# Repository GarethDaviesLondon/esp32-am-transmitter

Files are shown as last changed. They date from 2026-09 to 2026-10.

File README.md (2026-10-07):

# ESP32-S3 AM Transmitter

An ESP32-S3 plays internet radio over Wi-Fi and re-broadcasts it as an
amplitude-modulated longwave carrier on a GPIO pin, so an ordinary AM receiver
in the same room picks it up. Two independent transmitters, two stations, one
board. It is driven entirely from a web page it serves itself, or from a serial
console, and it lives in a 3D-printed case whose lid is the antenna.

**[There is a project page with a demo video.](https://garethdavieslondon.github.io/esp32-am-transmitter/)**

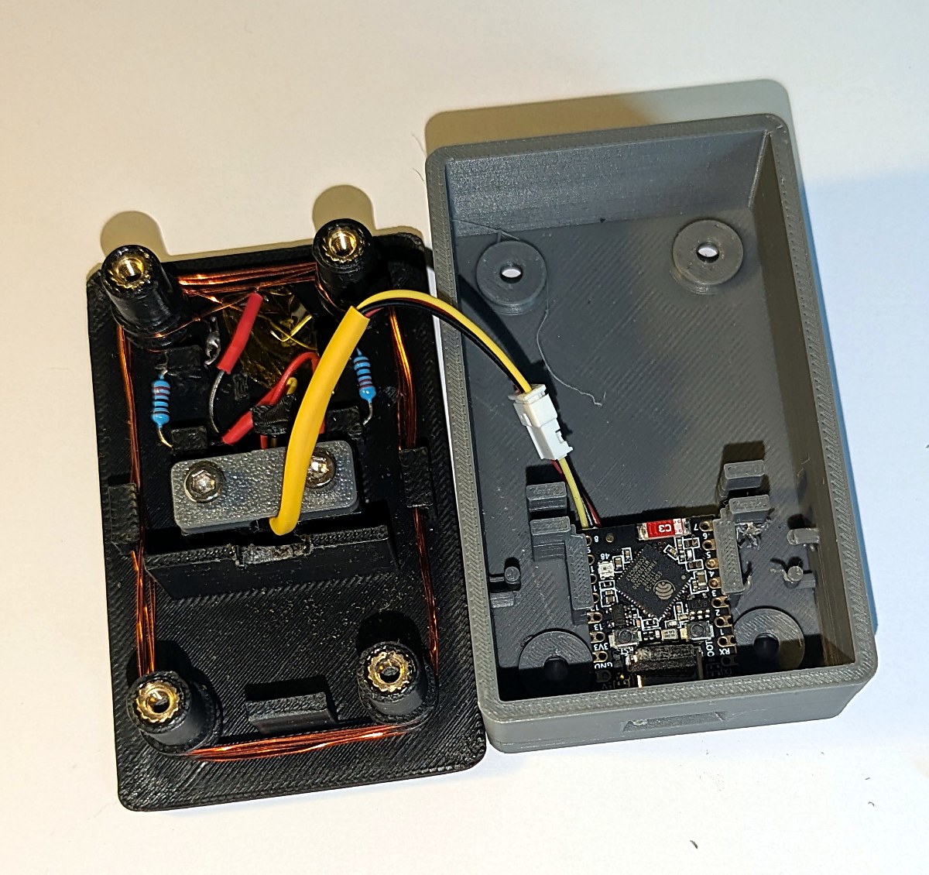
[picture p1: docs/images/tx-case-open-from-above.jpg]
The transmitter, open


## Read this before you build one

**This is a radio transmitter, and two facts about it are not negotiable.**

- **It transmits in a licensed broadcast band.** The default carrier is
  200 kHz, which is inside the longwave broadcast band, 2 kHz from BBC Radio 4
  on 198 kHz. Deliberate radiation there is licensed in the UK and in most
  other countries, and this project holds no licence. It is built to be heard
  by a receiver on the same table: an inductive loop beside the radio, not an
  antenna. **What you radiate, and the rules where you live, are yours to
  check.**
- **There is no output filter in this build.** The carrier is a square wave,
  so it radiates odd harmonics at 600 kHz, 1 MHz and upward, across the whole
  medium-wave band. At this power, with the loop next to the receiver, that
  was judged acceptable by ear. **It has never been measured on a spectrum
  analyser.** Raise the drive, lengthen the antenna or drop the series
  resistor and the harmonics rise with it. The Technical Manual gives a
  low-pass network to fit if you do.

## How it is wired

The as-built wiring

Per transmitter: a GPIO pin, a 220 ohm resistor, a five-turn loop wound on the
lid's pillars, back to ground. The two chains share the ground and nothing
else.

## What it does

- **Two transmitters.** Separate stations, carrier frequencies, modulation
  depth, audio low-pass, gain, carrier level and power-on station. They share
  one Wi-Fi connection and one station list.
- **Proper AM.** Duty-cycle modulation linearised through an arcsine table,
  because the obvious scheme barely modulates at all. A 6th-order low-pass,
  a fractional resampler with a fill controller, a peak limiter and a loudness
  AGC that brings stations within about 2 dB of each other.
- **A web interface** for everything: stations, directory search, both
  transmitters' settings, a test tone, Wi-Fi, diagnostics.
- **A serial console** that can do everything the page can, so a board whose
  network is broken is still reachable over USB.
- **Carrier level and fading**, if you want it to sound like a distant station.
- **A printed case** whose lid carries both loop windings on four pillars.

## Quick start: flash a board

You need a Waveshare ESP32-S3-Zero (or another ESP32-S3), a USB-C data cable,
and Python.

```
pip install esptool
python -m esptool --chip esp32s3 -p COM5 write_flash 0x0 binaries/amtx-v1.0-merged.bin
```

Use your own port (`/dev/ttyACM0` and similar elsewhere), and the board's own
USB-C socket rather than a separate serial adapter.

Then power it up, join the Wi-Fi network **`AMTX-Setup`** it raises, and follow
the page that opens.

If that was too terse, **[docs/manuals/quick_start.pdf](docs/manuals/quick_start.pdf)**
is the same journey with every step spelled out: installing Python, which of
the board's two USB sockets to use, the flashing tool in `tools/esp-flasher`,
proving the firmware is running by typing `help` at the `amtx>` console, and
both ways of putting the board on your network. No compiler needed.

## Build one

**[docs/manuals/build_manual.pdf](docs/manuals/build_manual.pdf)** is the
end-to-end guide: parts, printing, heat-set inserts, winding the antenna,
wiring, assembly, flashing, first boot, and what to do when it does not work.

| Manual | For |
| --- | --- |
| [Quick Start](docs/manuals/quick_start.pdf) | Release zip to a transmitter on the air, no toolchain. Start here |
| [Build](docs/manuals/build_manual.pdf) | Making one from parts |
| [Installation](docs/manuals/installation_manual.pdf) | Toolchain, building the firmware from source, flashing |
| [User](docs/manuals/user_manual.pdf) | Driving it once it runs |
| [Technical](docs/manuals/technical_manual.pdf) | How the firmware works, for changing it |

## What is in here

```
firmware/     ESP-IDF v5.3 project: the whole transmitter
tools/        Desktop tools, Python + tkinter:
                esp-serial-monitor   serial console, system and CLI panes split
                esp-flasher          finds, probes, flashes and monitors a board
                amtx-programmer      the flasher plus a tab that sets the board up
case/          The printed case: STEP for editing, STL for printing
binaries/      A flashable build, merged and as separate images
docs/          The manuals, as PDF and Markdown
```

## What has actually been tested

This project tries to be honest about the difference between "built" and
"proven". As of v1.0:

- **Runs on hardware.** Two stations playing at once, heard on an AM receiver,
  each decoder sustaining full rate with the modulator never starving. The web
  interface, the console, station switching, Wi-Fi joining and the diagnostics
  have all been used on a real board.
- **Printed and assembled.** The case has been printed and built more than
  once. The current revision fixes what the last print got wrong; **it has not
  itself been printed yet**, and nothing in it needs support.
- **Not measured.** Nothing has been on a spectrum analyser or a scope. The
  harmonic content, radiated field strength and modulation depth are unknown.
- **Not tested on hardware:** the factory-reset button gesture (hold BOOT for
  five seconds). The code is built and the other two routes to the same
  function are straightforward, but nobody has pressed the button yet.

## Licence

GPL-3.0. See [LICENSE](LICENSE).

The MP3 decoder (libhelix) is fetched by the build from the ESP component
registry and carries its own licence. The board's dimensions came from
Waveshare's published drawing for the
[ESP32-S3-Zero](https://www.waveshare.com/wiki/ESP32-S3-Zero), which is not
reproduced here.

## About this repository

It is the public mirror of a working repository where the engineering record
lives: design documents, the registers of known issues and lessons, the
parametric CAD source for the case, and the reasoning behind each decision.
What is published here is the product: source, tools, manuals, geometry and a
binary.

Issues and pull requests are welcome, though development happens elsewhere and
lands here in releases.

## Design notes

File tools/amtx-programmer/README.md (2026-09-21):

# Tool: amtx-programmer

## Purpose

Sets up an AM transmitter board from a PC, over USB, without the web page.

It is `esp-flasher` with one more tab. The flasher finds the board, reads what
is on it and writes firmware. The **Program** tab then configures the running
transmitter with buttons and dialogs: what each transmitter plays, its RF
settings, the station list, Wi-Fi, the hostname, and whether the web interface
is on at all. Every button sends a command to the board's `amtx>` serial
console and shows the reply.

It is for the cases the web page cannot cover: a board with the web interface
turned off, a board not yet on any network, or several boards to set up one
after another.

## In this project

- The commands are the ones in `docs/design/07_console_and_access.md` §2. The
  firmware must include them. On older firmware the tab connects, but most
  buttons answer "unrecognised command (is the firmware older than design
  07?)". Flash a current build first; the Flash section above the tab does
  that.
- The board's console is on native USB. The tab holds the port while it is
  connected, so it closes any monitor tab on the same board when you press
  **Connect**, and lets go while the flasher probes or flashes. Opening a
  monitor tab on the board takes the port back from the Program tab.
- After a reboot or a flash the board drops off the bus. The tab reconnects by
  itself when it comes back, for up to 20 seconds.

## Usage

```
pip install -r tools/amtx-programmer/requirements.txt
python tools/amtx-programmer/amtx_programmer.py
```

1. Plug the board in and select it in the board list at the top.
2. Open the **Program** tab and press **Connect**. The tab reads the board's
   state and fills in every sub-tab.
3. Use the sub-tabs:
   - **Transmitters**: what A and B are playing, Stop, Play a URL, every RF
     setting with **Apply and save**, and the test tone.
   - **Stations**: the shared list. Play on A or B, Add, Delete, Move up and
     down, level Trim, and the power-on station for each transmitter.
   - **Discover**: search Radio-Browser by name, genre or country, then play a
     result or save it to the list.
   - **Network and access**: Wi-Fi scan, join, save and forget; the hostname;
     turning the web interface on or off; the board's log output.
   - **Console log**: every command sent and every reply line, with log lines
     from the board marked `[SYS]`. A box at the bottom sends any command by
     hand.
4. **Refresh** reads the state again. It also happens after every change.
   Tick "Refresh every 5 s" to keep the view live.

Every reply shows in the status bar at the bottom of the tab. A command that
fails also opens a dialog saying why.

Without a board:

```
python tools/amtx-programmer/amtx_programmer.py --sim      # the GUI against a simulated board
python tools/amtx-programmer/amtx_programmer.py --check    # build the window, connect to the simulation, exit
```

One command from the command line, no window:

```
python tools/amtx-programmer/amtx_programmer.py --port COM5 --run "state"
python tools/amtx-programmer/amtx_programmer.py --run "station list"
```

## Files

The Program tab is split by panel: each mixin owns the widgets it builds, the
part of the state document it renders, and what its buttons do. Adding a
control means opening the file named after the thing it controls.

| File | Holds |
| ---- | ----- |
| `amtx_programmer.py` | the command line and the window |
| `amtx_console.py` | the console as a request and reply protocol, no Tk in it |
| `programmer_config.py` | constants, and the flasher and monitor imports |
| `programmer_tab.py` | the Program tab: connection, worker thread, refresh |
| `programmer_transmitters.py` | the two transmitter panels and the test tone |
| `programmer_stations.py` | the station list panel |
| `programmer_discover.py` | the Radio-Browser panel |
| `programmer_network.py` | Wi-Fi, hostname, web interface, reboot |
| `programmer_dialogs.py` | the form dialog they all ask with |
| `fake_board.py` | a simulated board, for the tests and `--sim` |

## How it talks to the console

`amtx_console.py` is the protocol, with no GUI in it:

- **A reply ends at `ok` or `error:`** for every command design 07 added.
- **`wifi`** ends with one too. `wifi join` and `wifi scan` wait up to 25
  seconds for it, because a join can be silent for 15.
- **`status`, `log` and `reboot`** print no such line. Their reply ends when
  the console prints its `amtx>` prompt again, which the REPL does before
  reading every line, or after a short quiet period if the prompt never shows.
  `reboot` ends at "rebooting" or when the port drops.
- **The console asks the terminal where its cursor is** (`ESC[6n`) before
  every line, and waits for the answer with no timeout, reading anything sent
  meanwhile as the answer. The reader answers those queries itself, as the
  monitor's terminal does. Without that, commands are swallowed.
- **Log lines are separated** with `esp-serial-monitor`'s `ConsoleSplitter`,
  imported, not copied.
- **On connecting** it sends an empty line and waits for a fresh prompt, which
  also clears anything half-typed in the console.

`fake_board.py` is a model of that console, for the tests and for `--sim`: a
smart and a dumb terminal mode, coloured log lines in the middle of replies,
the REPL's own error trailer, and a reboot that takes the port away. Where the
firmware's wording differs from it, the firmware is right.

## Tests

The repo's root `python -m pytest` collects only `cad/` and `designs/`, so run
these by path:

```
python -m pytest tools/amtx-programmer
```

34 tests: text parsing, every command in both terminal modes against the
fake board, a failure not leaking into the next reply, a disconnect in the
middle of a command, reboot and reconnect, and the Program tab itself driven
with its window hidden. The GUI tests skip where Tk cannot open a window.

## Dependencies

- `pyserial` and `esptool`, through `tools/esp-flasher/requirements.txt`.
- `tools/esp-flasher/` and `tools/esp-serial-monitor/` must sit beside this
  directory; the program imports both.
- `pytest`, for the tests only.

## Redeployable?

`partly`. `amtx_console.py`'s reply handling suits any ESP-IDF `esp_console`
REPL whose commands print a final `ok` or `error:` line; `PROMPT` and the
legacy command list are the project-specific parts. The Program tab and
`fake_board.py` are this firmware's command set and nothing else.

## What has been verified

- **In this session, with no board:** the test suite passes (34 tests, run
  more than twenty times in a row after the last change). `--check` builds the
  window, connects to the simulated board and shows its stations.
- **Not verified:** nothing has run against a real board. The firmware with
  the design 07 commands had not been flashed anywhere when this was written,
  so every reply format here comes from the design document and ESP-IDF's
  REPL source, not from a board. The dialogs have been built and driven by the
  tests but not looked at by a person.
- One test run failed, once, before the `--check` test moved into its own
  process, and its output was not captured. A second Tk window in the same
  process had also been failing to start intermittently at that point, which
  is the likely cause, but it is not proven.

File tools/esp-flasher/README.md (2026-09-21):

# Tool: esp-flasher

## Purpose

A flashing console for ESP32 boards that works out what the board needs
instead of making you know. It:

1. **Watches the USB bus** and flags a board that keeps dropping off it, which
   is what a blank or corrupt ESP32-S3 on native USB does.
2. **Catches the board in download mode**, retrying on every reappearance, so a
   boot-looping board can be reached without holding BOOT.
3. **Reads back what is on the flash** (bootloader, partition table, app
   description) and compares each with the build you picked.
4. **Recommends what to write**: bootloader, partition table and app when the
   board is blank or its layout differs, the app alone when the rest already
   matches. It refuses a build for the wrong chip or a bigger flash.
5. **Flashes it** with esptool, and **opens a serial monitor tab** that follows
   the board through resets, so you see it boot and can use the `amtx>` CLI.

The monitor tabs are `tools/esp-serial-monitor`'s, imported rather than copied,
with reconnection added.

## In this project

- Pick the `build/` directory that `idf.py build` produced. The tool reads
  `build/flasher_args.json`, so it writes the same three images at the same
  offsets and flash settings `idf.py flash` would.
- The board is on native USB (`303A:1001`). The tool tracks it by the USB
  serial number, which is the chip's MAC, so it follows the board even if
  Windows hands it a different COM number after a reset. The baud rate is
  cosmetic on this port.
- A **new, blank board** shows `boot-looping (resets every 2.6s)` in the board
  list. On the bus for about 2.2 s, then gone for 0.4 s, while the ROM prints
  `invalid header: 0xffffffff` until the watchdog resets it. See `LL-06`.

## Usage

GUI (the normal way):

```
python tools/esp-flasher/esp_flasher.py
```

1. **Board.** Plug the board in; it appears in the list (a looping one too).
   Press **Probe board**. The probe is read-only; it reports the chip, flash
   size, MAC, and the state of each region against the selected build. A board
   with an app is reset back into it; a blank one is left in download mode,
   where it stops looping and stays on the bus.
2. **Firmware.** The newest `build*/` directory under the repo is preselected.
   **Build folder...** picks another, **.bin file...** picks a single image
   (a merged image goes at 0x0, anything else at the offset in the box).
3. **Flash.** Leave **Auto** on and press **Flash**. If the board has not been
   probed, it is probed first. A confirmation lists exactly what will be
   written and why. **Erase whole flash first** also wipes NVS: saved Wi-Fi
   networks and settings.
4. When the board comes back on the bus, a **Monitor** tab opens on it: logs
   and boot output in the `[SYS]` pane on top, the `amtx>` console in the
   terminal pane below (click it and type). If the board resets, the tab
   reconnects by itself unless you closed the port.

Command line, for the same operations without the window:

```
python tools/esp-flasher/esp_flasher.py --list              # ESP boards on the bus
python tools/esp-flasher/esp_flasher.py --watch 10          # appear/vanish log, spots a boot loop
python tools/esp-flasher/esp_flasher.py --builds            # build directories found
python tools/esp-flasher/esp_flasher.py --probe             # what is on the board vs the newest build
python tools/esp-flasher/esp_flasher.py --flash             # probe, confirm, write what it needs
python tools/esp-flasher/esp_flasher.py --flash --mode app --port COM5 --build build -y
```

A probe of a blank board, as seen on the second bench board (2026-09-16):

```
ESP32-S3 (QFN56) (revision v0.2)  MAC aa:bb:cc:dd:ee:ff  flash 4MB
Features: Wi-Fi, BT 5 (LE), Dual Core + LP Core, 240MHz, Embedded Flash 4MB (XMC), Embedded PSRAM 2MB (AP_3v3)
Bootloader: blank
Partition table: blank
App: no app partition to look in
Board left in download mode (it will not run until flashed or reset).
Recommended: full (the board has no bootloader)
```

## Files

| File | Holds |
| ---- | ----- |
| `esp_flasher.py` | the command line, and the names amtx-programmer imports |
| `flasher_config.py` | constants, the monitor and esptool imports, `Cancelled` |
| `flasher_images.py` | parsing an image header, an app description, a partition table |
| `flasher_firmware.py` | a build on disk, and finding builds |
| `flasher_bus.py` | watching the USB bus, spotting a boot loop (`LL-06`) |
| `flasher_probe.py` | catching the board, reading it back, comparing with a build |
| `flasher_esptool.py` | running esptool, and its v4/v5 differences |
| `flasher_ui.py` | the window, and the monitor tab that reconnects |

## Dependencies

```
pip install -r tools/esp-flasher/requirements.txt
```

- `esptool` (v4.7 or v5) and `pyserial`. Probing uses esptool as a library;
  flashing runs `python -m esptool` as a child process, so Stop can kill it and
  its output streams into the log.
- `tools/esp-serial-monitor/esp_serial_monitor.py` must sit beside this
  directory; the monitor tabs come from it.
- The ESP-IDF Python environment already has both packages, so the tool also
  runs from an `export.ps1` shell.

## Redeployable?

`yes`, together with `esp-serial-monitor`. Nothing is specific to this project:
the image layout comes from the build's `flasher_args.json` and the image
headers. Worth a `TUNE:` look for another board:

- `CHIP_IDS`: the image-header chip ids recognised; an unknown one is shown by
  number and still flashes.
- `CONNECT_TIMEOUT`, `PORT_POLL_SECONDS`, `LOOP_WINDOW_SECONDS`: tuned for an
  S3 that is off the bus for 0.4 s per loop.

## Notes

- **The tool closes its own monitor tab before probing or flashing** and
  reopens it afterwards. A terminal in another program still blocks the port;
  close it first.
- **Auto recommends app-only only when the bootloader and partition table on
  the board are byte-identical to the build's.** Anything else gets a full
  flash, which is always safe.
- **A changed partition table can orphan NVS.** The recommendation says so;
  tick Erase if the board misbehaves after a layout change.
- **Early boot lines can be missed.** Native USB re-enumerates after the reset
  that follows a flash, and nothing is read until the port is back. Press the
  board's RESET with the tab open to see a whole boot.
- **If the board cannot be caught** within 25 s, put it in download mode by
  hand: hold BOOT, press and release RESET, release BOOT, then probe again.
- **What has been exercised on hardware:** listing, bus watch, probing a blank
  board (CLI and GUI), the GUI's plan, and a monitor tab opening. Not
  exercised: catching a board **while** it boot-loops using this finished tool
  (the same retry loop did catch it in a prototype on the second attempt),
  the flash itself, the post-flash reconnect, and esptool v4.

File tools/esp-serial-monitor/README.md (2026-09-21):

# Tool: esp-serial-monitor

## Purpose

A serial console for ESP32/ESP8266 development boards that answers the two
questions a terminal program makes you answer first: **which port is the board
on, and what baud rate is it talking at?** It lists the ports, marks the ones
whose USB adapter belongs to an ESP board, probes a port to work out its baud
rate from the traffic itself, and opens a monitor tab per board with keyboard
entry back to the device.

Each monitor tab has **two panes**. The top one collects **system messages**,
each line prefixed `[SYS]`: ESP-IDF log lines (`I (1234) wifi: ...`, coloured
by level), ROM banners (`rst:`, `invalid header`) and crash dumps, plus the
monitor's own notices. The bottom one is a **terminal for the board's
console**: click in it and type, PuTTY style. It understands the escape
sequences ESP-IDF's line editor sends and answers its terminal probe, so arrow
keys, history and TAB completion work.

It removes the loop of guessing a COM port, guessing 115200, seeing garbage and
guessing again. It also watches several boards at once in one window, which
`pio device monitor` will not do and a mesh or multi-node bring-up needs.

## In this project

The board is an ESP32-S3 with the console on **USB Serial/JTAG**, not a UART
(`CONFIG_ESP_CONSOLE_USB_SERIAL_JTAG=y` in `sdkconfig.defaults`). Two
consequences when you use this tool here:

- The port shows up as `Espressif native USB (JTAG/serial)` (VID `0x303A`, PID
  `0x1001`), already in `KNOWN_ADAPTERS`, so it is flagged as a likely ESP board
  without any tuning.
- **The baud rate is cosmetic.** It is a USB CDC link, so any rate works and
  "Detect baud..." has nothing real to measure. Open the monitor at 115200 and
  ignore the rate; the tool says the same thing when it recognises the adapter.

Reset-pulse caveat: the native USB port has no DTR/RTS auto-reset transistors,
so "Reset board while probing" does nothing here. Press the board's EN button,
or reflash, to see the boot banner.

The value of the tool on this project is the multi-board case: with two
transmitters under test, or a board and a receiver-side jig, it watches both in
one window, which `idf.py monitor` will not do. It is also the way to read the
log when `idf.py monitor` is unavailable (no ESP-IDF export in that shell, or a
Windows session outside the IDF environment).

## Usage

GUI (the normal way):

```
python3 tools/esp-serial-monitor/esp_serial_monitor.py
```

1. **Boards** lists every serial port, likely ESP boards first, with the adapter
   it recognised (CP210x, CH340, FTDI, or the S2/S3/C3 native USB). Tick
   "Likely ESP boards only" to hide Bluetooth and modem ports.
2. Select a port and click **Detect baud...** if you do not know the rate. It
   tries each candidate rate in turn, scores what comes back for readability,
   and ranks them. Double-click the winning row to open a monitor at that rate.
3. Or set the rate yourself and click **Open monitor**. Select several ports and
   they all open, one tab each.
4. Click in the **Console** pane and type. Every keystroke goes to the board as
   you press it: the arrow keys as ANSI sequences, TAB for completion, Ctrl+C
   as `0x03` (or a copy, when text is selected), Ctrl+V pastes to the board.
   What appears is the board's own echo. **Enter sends** CR by default, which
   is what ESP-IDF's console reads as Enter; switch it to LF or CRLF for
   firmware that wants those. The **Send line** box under the pane sends a
   whole line at once, with its own history.
5. System messages land in the top pane as they arrive, even in the middle of a
   half-typed command, so the console stays readable. Untick **Split system
   messages** to see the raw interleaved stream in the terminal instead.

Command line, for the same discovery without the window:

```
$ python3 tools/esp-serial-monitor/esp_serial_monitor.py --list
PORT       ADAPTER                            ESP?    DESCRIPTION
COM18      Espressif native USB (JTAG/serial) yes     USB Serial Device (COM18)
           USB VID:PID=303A:1001 SER=AA:BB:CC:DD:EE:FF
COM3       Bluetooth virtual port             -       Standard Serial over Bluetooth link (COM3)

$ python3 tools/esp-serial-monitor/esp_serial_monitor.py --detect COM18
Probing COM18 (Espressif native USB (JTAG/serial))
  Trying 115200 baud...
  115200 baud: 412 bytes, score 1.10
  Confident match at 115200 baud; stopping.

BAUD      BYTES   PRINTABLE  SCORE  SAMPLE
115200    412     100%       1.10   I (325) cpu_start: Pro cpu up. | I (330) app_main: running

Best match: 115200 baud.
```

`--detect` with no port picks the board itself if exactly one is plugged in.
Other flags: `--bauds 115200,74880` to probe a specific list, `--seconds` to
listen longer at each rate, `--no-reset` to listen without restarting the board,
`--all-bauds` to probe every rate instead of stopping at the first confident
match, `--esp-only` to filter `--list`.

### What each monitor tab gives you

| Control | Does |
| --- | ---- |
| Baud + Apply | change rate on a live port, without reopening it |
| DTR / RTS | drive the control lines by hand, for boards with unusual wiring |
| Reset board | pulse the auto-reset circuit so you see the boot banner |
| Send break | assert a UART break, for firmware that uses one as a signal |
| Close port / Reopen | free the port for a flash, then pick the session back up |
| Split system messages | route log lines, ROM output and crash dumps to the `[SYS]` pane; off sends everything to the terminal |
| Timestamps | prefix each system line with local time to the millisecond |
| Hex view | 16-column hex dump of every byte in the system pane, for binary protocols |
| Pause | freeze the display while the port keeps draining |
| Log file | append to a file as it arrives: `[SYS]` system lines, `[CLI]` finished console lines |
| Enter sends | CR, LF or CRLF, for the Enter key in the terminal and the Send line box |
| Escapes | interpret `\n`, `\r`, `\t`, `\0`, `\xHH` in the Send line box |
| Local echo | also show what the Send line box sent, for firmware that does not echo |

## Files

One job per module. `esp_serial_monitor.py` is the command line and the front
door, and the names other tools use are re-exported from it, so
`import esp_serial_monitor as monitor` keeps working whatever moves below.

| File | Holds |
| ---- | ----- |
| `esp_serial_monitor.py` | the command line, and the public surface |
| `monitor_config.py` | constants, and whether pyserial is installed |
| `monitor_ports.py` | finding, describing and opening a port |
| `monitor_baud.py` | working out a board's baud rate by listening |
| `monitor_session.py` | one open port, read on its own thread |
| `monitor_split.py` | telling log output from console output |
| `monitor_terminal.py` | the VT100 subset linenoise needs |
| `monitor_text.py` | key names, escapes, hex rows, timestamps |
| `monitor_tab.py` | one board's tab and its two panes |
| `monitor_app.py` | the window, the port list, the detect dialog |

Module names are prefixed `monitor_` because these tools are scripts on
`sys.path` rather than packages: the flasher puts its own directory and this
one on the path together, and two modules with the same name would shadow each
other.

## Dependencies

```
pip install -r tools/esp-serial-monitor/requirements.txt
```

- `pyserial` for port enumeration and I/O. Everything else is the standard
  library (`tkinter`; on some Linux distributions install it separately with
  `sudo apt install python3-tk`).
- Linux users need to be in the `dialout` group to open a port, or every open
  fails with a permission error.
- No network access. The tool writes to the board only what you type, plus the
  reset pulse when you ask for one.

## Redeployable?

`yes`. No project-specific paths and nothing to tune for a normal ESP project.
Two constants are worth a `TUNE:` look for an unusual board:

- `KNOWN_ADAPTERS`: add the VID/PID of a bridge chip the project's boards use if
  it is not in the list. An unlisted adapter still works; it just is not flagged
  as a likely ESP board.
- `DEFAULT_PROBE_BAUDS` / `COMMON_BAUDS`: trim to the rates the project's
  firmware actually uses to make detection quicker.

If the project pins a `monitor_speed` in `platformio.ini`, that is the rate the
firmware talks at; detection is for the boards where nobody wrote it down.

Neither was tuned for this project: `KNOWN_ADAPTERS` already carries the S3's
native-USB VID/PID, and the probe list is irrelevant on a USB CDC link.

The two-pane monitor (the system/console split and the terminal emulation) was
added here, after the tool was installed from the catalogue, so the live copy
is now ahead of the catalogue copy. None of it is project-specific: it keys on
the ESP-IDF log format and the escape sequences of ESP-IDF's `linenoise`, so it
back-ports as is.

## Notes

- **Detection needs the port free and the board talking.** It opens the port
  exclusively, so close any other monitor first (the tool says so plainly when
  the open fails). If the firmware prints nothing at boot, every rate comes back
  silent and the tool says that rather than guessing.
- **The reset pulse assumes the standard auto-reset wiring** (DTR to IO0, RTS to
  EN). It holds IO0 high so the board restarts into the application, not the ROM
  bootloader. A board without those transistors ignores it; untick "Reset board
  while probing" and detection just listens.
- **On the S2/S3/C3 native USB port the baud rate is cosmetic.** It is a USB CDC
  link, not a real UART, so any rate works and the tool says so. Baud only
  matters on a board with a separate bridge chip.
- **A board that sends non-ASCII log output scores lower** than a plain ASCII
  one, because the score rewards printable bytes. Read the sample column rather
  than trusting the score alone.
- Opening a port resets many boards, whatever this tool does with DTR/RTS: that
  is the adapter's wiring, not the software. Expect to see a boot banner.
- The tool never flashes firmware. Close the port (or the tab) before flashing,
  or the flasher cannot claim it.
- Each pane keeps the last 5000 lines. Turn on a log file for a long run.
- **How a line is judged a system message:** it starts with the ESP-IDF log
  format (`I (1234) tag: `, optionally coloured), or with a known ROM or panic
  prefix (`rst:`, `ESP-ROM:`, `Guru Meditation`, `Backtrace:` and so on), or a
  coloured log line starts in the middle of console text. Text that might be
  the start of one is held back for at most 0.15 s, so typing does not lag.
  With `CONFIG_LOG_COLORS` off, a log line printed over a half-typed prompt is
  not recognised and stays in the terminal.
- **The terminal emulates a small VT100 subset:** CR, LF, backspace, tab,
  erase in line, cursor movement, clear screen, colours, and the `ESC[5n` /
  `ESC[6n` status queries. That is what ESP-IDF's console uses. A full-screen
  program would need more.
- **Line editing depends on the probe at boot.** ESP-IDF asks the terminal
  whether it understands escape sequences when the console starts. If no
  terminal was listening then (the port was closed during boot), the console
  falls back to "dumb" mode for that boot: typing still works, but the arrow
  keys and history do not. Reboot with the tab open to get line editing.

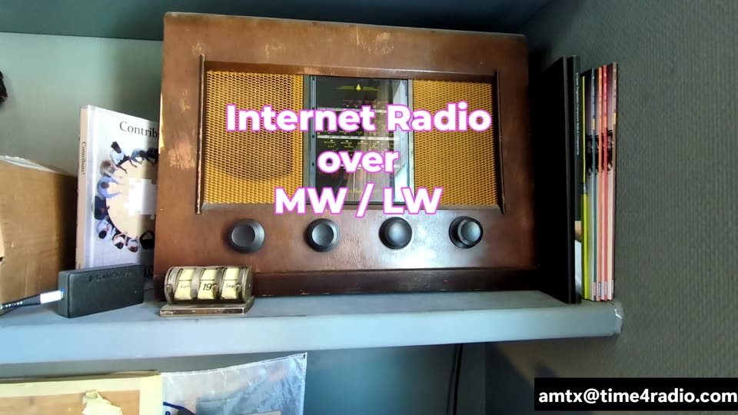
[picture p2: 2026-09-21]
docs/media/amtx-demo-poster.jpg

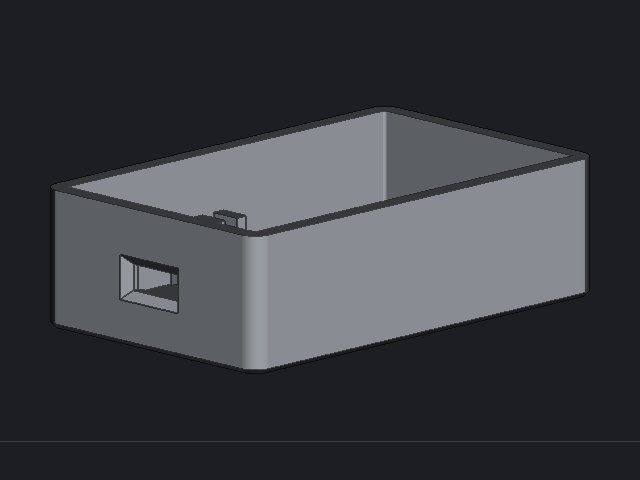
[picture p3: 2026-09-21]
docs/images/renders/base.jpg

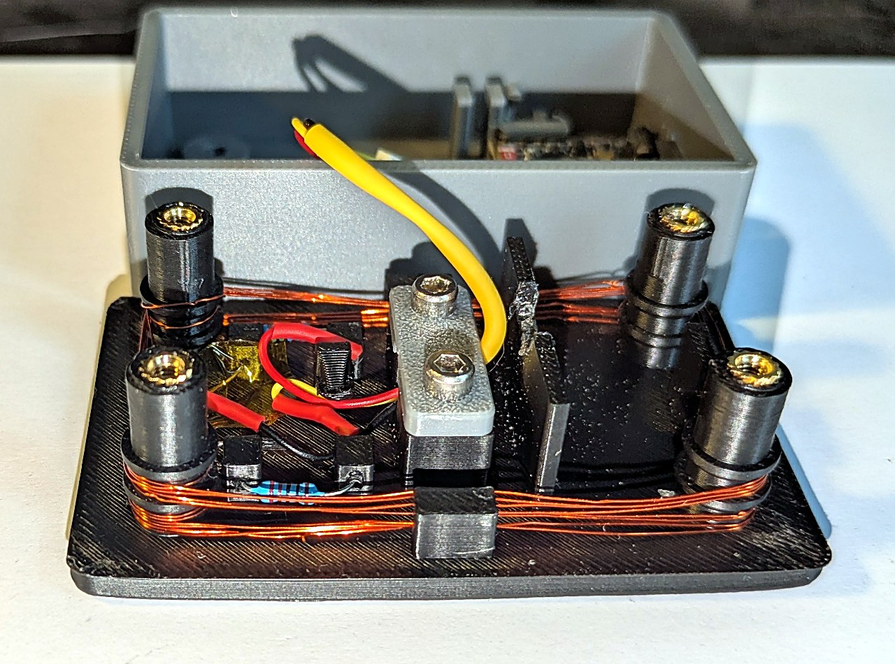
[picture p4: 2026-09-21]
docs/images/tx-case-windings-close.jpg

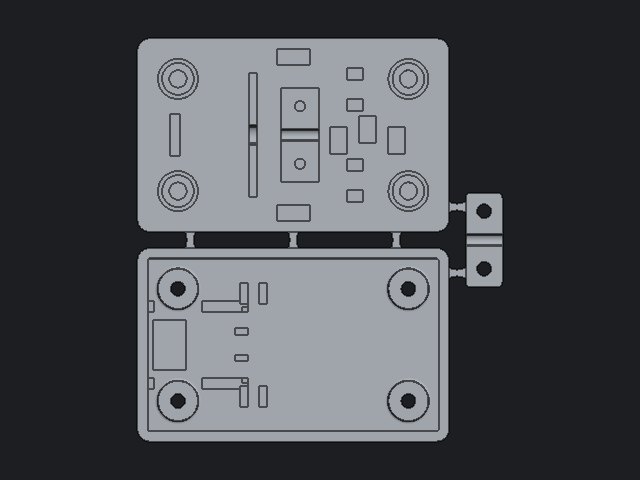
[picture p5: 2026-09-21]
docs/images/renders/sprue.jpg

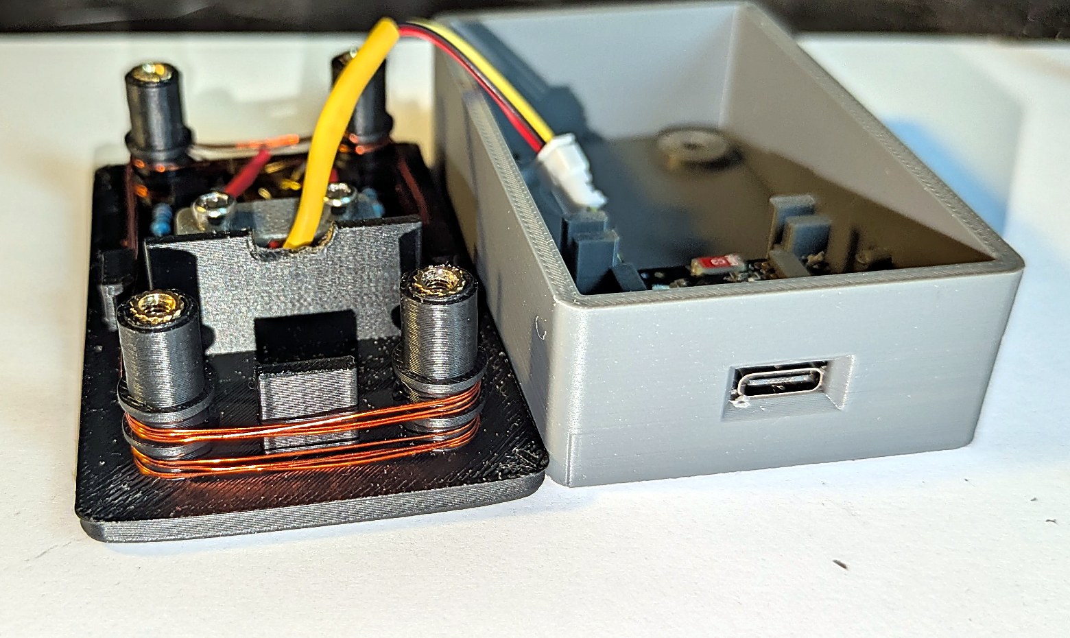
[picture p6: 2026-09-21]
docs/images/tx-case-lid-and-base.jpg

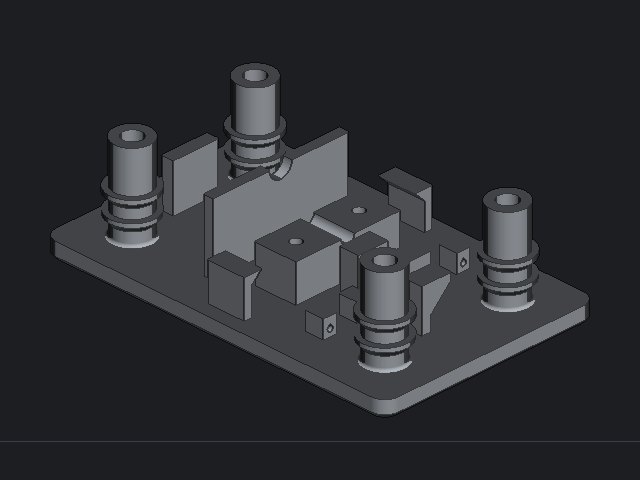
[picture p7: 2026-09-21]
docs/images/renders/lid.jpg

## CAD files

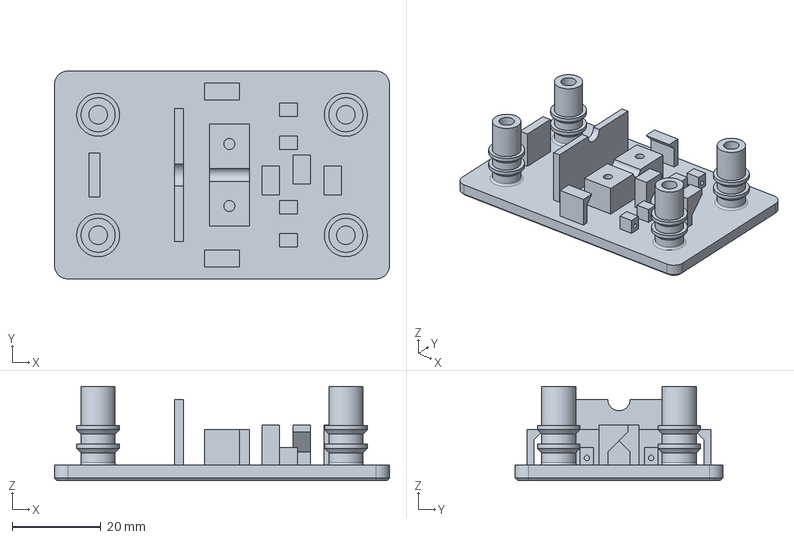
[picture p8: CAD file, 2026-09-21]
case/tx-case.lid.step
75.6 x 46.9 x 21.3 mm

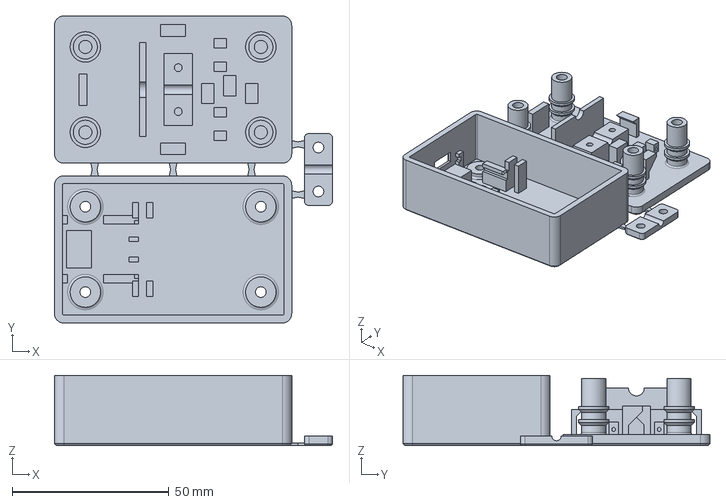
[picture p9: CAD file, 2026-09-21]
case/tx-case.sprue.step
88.6 x 97.8 x 22.3 mm

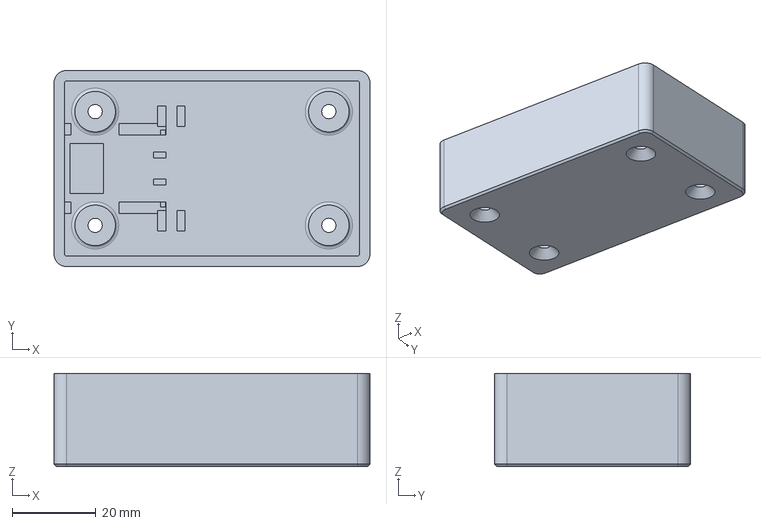
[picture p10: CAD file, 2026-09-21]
case/tx-case.base.step
75.6 x 46.9 x 22.3 mm

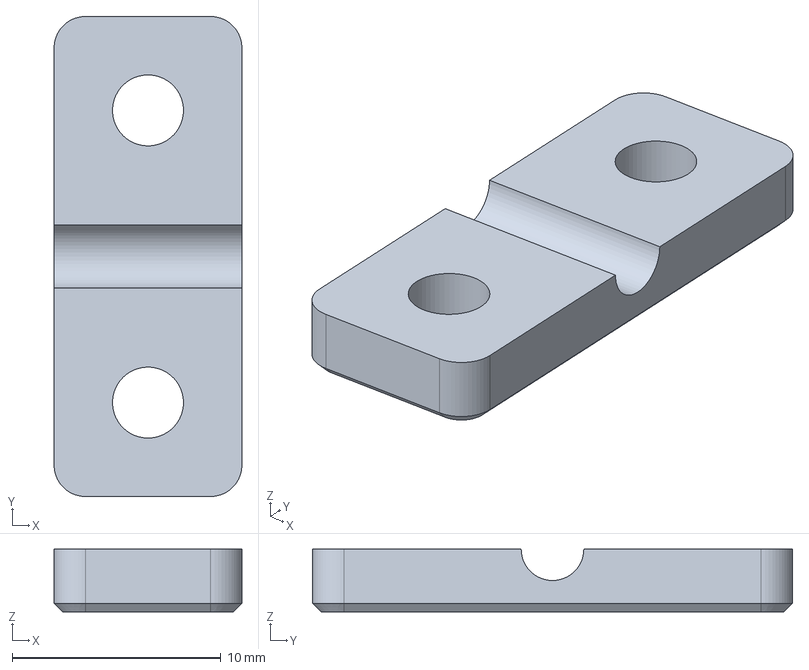
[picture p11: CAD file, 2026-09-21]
case/tx-case.clamp.step
9.00 x 23.0 x 3.00 mm

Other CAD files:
case/tx-case.base.stl
case/tx-case.clamp.stl
case/tx-case.lid.stl
case/tx-case.sprue.stl

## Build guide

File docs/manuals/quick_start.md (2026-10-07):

# Quick Start

From a downloaded release to a transmitter playing internet radio, with no
compiler and no ESP-IDF. About twenty minutes, most of it waiting for
downloads.

This is the short path. It flashes a firmware binary that is already built.
If you want to change the firmware and build it yourself, read the
Installation Manual instead. To make the case and wind the antennas, read the
Build Manual.

## Contents

1. What you need
2. Get the release
3. Install Python
4. Plug the board in
5. Flash it
6. Talk to the board
7. Put it on your Wi-Fi
8. Hear something
9. Before you leave it running
10. When it goes wrong

## 1. What you need

| Item | Notes |
| ---- | ----- |
| An ESP32-S3 board | 8 MB flash. A bare "mini" dev board is fine. No display, no audio hardware, no buttons needed |
| A USB cable | Data, not charge-only. A charge-only cable looks like a dead board |
| A Wi-Fi network | 2.4 GHz. The board has no 5 GHz radio |
| An AM receiver | Longwave capable, if you keep the default 200 kHz and 250 kHz carriers |
| A PC | Windows, macOS or Linux |

You do **not** need the 3D-printed case, the loop antennas or any soldering to
get to the end of this guide. The board will transmit a few centimetres on its
own, which is enough to prove it works with a receiver sitting next to it.

### One thing to get right before anything else

Your board probably has two USB sockets. One is a USB-to-serial bridge
(CH343, CP210x or similar). The other is the ESP32-S3's own USB peripheral.

**Use the native USB port.** The firmware puts its console there. On the
bridge you will see the ROM bootloader banner and nothing else, and you will
conclude the board is broken when it is not.

On Windows the native port appears in Device Manager as
`USB JTAG/serial debug unit`, with a `USB Serial Device` COM number. On Linux
it is usually `/dev/ttyACM0`, on macOS `/dev/cu.usbmodem*`.

If the board has only one socket, that is the native one.

## 2. Get the release

Go to the [latest release](https://github.com/GarethDaviesLondon/esp32-am-transmitter/releases/latest)
and download the **source code zip**, not just the loose `.bin` files. The zip
carries the flashing tool as well as the firmware, and you want both.

Unzip it anywhere. You will end up with a directory holding, among other
things:

```
binaries/
  amtx-v1.0-merged.bin        the firmware, everything in one file
tools/
  esp-flasher/                the flashing tool you are about to run
  esp-serial-monitor/         the serial terminal it uses
docs/
  manuals/                    this guide and the other four
```

The version number in the `.bin` filename will match the release you
downloaded, so `amtx-v1.0-merged.bin` may read `v1.1` or later. Use whatever
is actually there.

## 3. Install Python

The flashing tool is a Python program. It needs **Python 3.10 or newer**.

- **Windows:** install from [python.org](https://www.python.org/downloads/).
  On the first screen of the installer, tick **Add python.exe to PATH**. This
  is the step everybody misses, and without it the commands below report
  `python: command not found`.
- **macOS:** `brew install python`, or the python.org installer.
- **Linux:** Python 3 is already there. You also need Tk, which is packaged
  separately: `sudo apt install python3-tk` on Debian or Ubuntu. Without it
  the tool stops with `ModuleNotFoundError: No module named 'tkinter'`.

Check it:

```
python --version
```

If that reports Python 2, or nothing, try `python3 --version` and use
`python3` everywhere below.

Now install the two packages the tool needs. From the directory you unzipped:

```
pip install -r tools/esp-flasher/requirements.txt
```

That is `pyserial`, which finds the board, and `esptool`, which writes the
flash. Nothing else.

## 4. Plug the board in

Connect the board's native USB port to the PC.

**A brand-new board will look broken.** A blank ESP32-S3 has nothing to boot,
so the ROM gives up and the watchdog resets it, about every 2.6 seconds. On
native USB that means the board appears on the bus, vanishes, and appears
again, over and over. Windows may chime repeatedly. This is correct behaviour
for an empty board and the flasher is built to cope with it.

## 5. Flash it

Change into the flasher's directory and run it:

```
cd tools/esp-flasher
python esp_flasher.py
```

Note the underscore in `esp_flasher.py`.

A window opens with three sections: Board, Firmware, Flash.

1. **Board.** Your board is in the list. A new one is labelled something like
   `boot-looping (resets every 2.6s)`, which is the tool telling you it has
   noticed the loop in §4. Select it and press **Probe board**.

   The probe only reads. It reports the chip, the flash size, the MAC address,
   and what is currently in each region. A blank board reports
   `Bootloader: blank` and is left in download mode, where it stops looping
   and sits still on the bus.

2. **Firmware.** The tool preselects the newest `build*/` directory it can
   find. **A release download has no `build/` directory**, so there will be
   nothing selected or the wrong thing selected. Press **`.bin` file...** and
   choose `binaries/amtx-v1.0-merged.bin` from the unzipped release.

   The tool recognises a merged image and places it at offset `0x0` by itself.
   You do not need to touch the offset box.

3. **Flash.** Leave **Auto** ticked and press **Flash**. A confirmation lists
   exactly what it is about to write and why. Accept it.

   Writing takes a few seconds. Leave **Erase whole flash first** unticked:
   on a new board there is nothing to erase, and on a used board it also wipes
   saved Wi-Fi networks and settings.

When the board comes back on the bus, a **Monitor** tab opens on it by itself.

### If you would rather not use the tool

The flasher is the friendlier route, but the plain `esptool` command does the
same job in one line, and it is the route that has had the most use on real
hardware:

```
pip install esptool
python -m esptool --chip esp32s3 -p COM5 write_flash 0x0 binaries/amtx-v1.0-merged.bin
```

Replace `COM5` with your port. On Linux that is `/dev/ttyACM0`, on macOS
`/dev/cu.usbmodem*`.

## 6. Talk to the board

The Monitor tab has two panes. Boot output and log messages scroll in the
`[SYS]` pane on top. The console is the terminal pane below.

**Click the lower pane before you type.** Keystrokes go to whichever pane has
focus, and typing into the log pane does nothing at all, which is a
dispiriting way to start.

You should see the board boot, join nothing yet, and settle. Press Enter and
you get the prompt:

```
amtx>
```

Log messages keep scrolling past while you type, which makes the console hard
to read. Turn them off:

```
amtx> log off
```

Now check the firmware is really running and talking to you:

```
amtx> help
```

That lists every command the board understands, in alphabetical order. You
should see `play`, `station`, `rf`, `tone`, `discover`, `wifi`, `hostname`,
`web`, `status`, `state`, `log`, `factory-reset` and `reboot`.

**If `help` lists those commands, the firmware is on the board and working.**
That is the milestone. Everything from here is configuration.

One more worth trying, because it prints the whole state of the board on one
line:

```
amtx> status
```

## 7. Put it on your Wi-Fi

The board has no network yet. There are two ways to give it one. They reach
the same result and save to the same place, so use whichever suits you.

### Option A: the setup page, from a phone

Best if you are away from the PC, or setting up a board that is already in its
case.

With no saved network, the board raises its own open Wi-Fi access point called
**`AMTX-Setup`**.

1. On a phone or laptop, join `AMTX-Setup`. It has no password.
2. The setup page opens by itself, as a captive portal. If it does not, open a
   browser and go to `http://192.168.4.1`.
3. Press **Scan**, pick your network, type its password, and save.
4. The board reboots and joins.

Once it has joined, the access point goes away and the board is at
**`http://amtx.local`**, or at the address shown on the page's Network tab.
That page is the full interface: stations, both transmitters, RF settings,
diagnostics.

### Option B: the console, from the PC

Best if you are already sitting at the Monitor tab, which you are.

See what is in range:

```
amtx> wifi scan
```

You get a numbered list with signal strengths:

```
 0  MyNetwork                        -52 dBm  secured
 1  BTWifi-X                         -78 dBm  open
ok: 2 network(s) found
```

Then join, which also saves:

```
amtx> wifi join MyNetwork mypassword
```

It prints `joining "MyNetwork" ...`, takes up to fifteen seconds, and then
tells you what happened:

```
joined "MyNetwork", ip 192.168.1.42, rssi -52 dBm
ok: joined MyNetwork, ip 192.168.1.42, saved (1 stored)
```

Put double quotes round anything containing a space:

```
amtx> wifi join "My Home Network" "pass phrase with spaces"
```

Useful companions:

| Command | Does |
| --- | ---- |
| `wifi status` | Where it is now, and its address |
| `wifi list` | The networks it has saved |
| `wifi save <ssid> [pass]` | Save for next boot without joining now |
| `wifi forget` | Delete every saved network |

A joined board prints its address. Open `http://amtx.local` in a browser and
you have the web interface, the same as Option A.

## 8. Hear something

A factory-fresh board comes up with two stations already in its list, one on
each transmitter:

| Transmitter | Default station | Default carrier |
| --- | --- | --- |
| A | Radio Swiss Jazz | 200 kHz |
| B | BBC World Service | 250 kHz |

So once it is on your network it should already be transmitting. Check with:

```
amtx> status
```

Now tune a receiver. Put it next to the board, switch it to **longwave**, and
tune slowly around 200 kHz. Without an antenna the range is a few centimetres,
so the receiver needs to be touching or nearly touching the board.

If you are hunting for the carrier and want something unmistakable, a steady
tone is far easier to find than music:

```
amtx> tone a on 1000
```

That replaces the programme on transmitter A with a 1 kHz tone. Find it on the
dial, then put the music back:

```
amtx> tone a off
```

Heard it? That is the whole chain working: Wi-Fi, the stream, the decoder, the
modulator and the carrier.

For everything you can do from here, read the User Manual.

## 9. Before you leave it running

Two things to understand, and they are not formalities.

**It transmits in a licensed broadcast band.** Longwave runs from 148.5 kHz to
283.5 kHz. The default 200 kHz carrier sits inside it, a couple of kilohertz
from BBC Radio 4's allocation on 198 kHz. Deliberate radiation there needs a
licence in the UK and in most other places, and this project has none. Keep
the field inside the room: no outdoor wire, nothing connected to mains wiring,
nothing resembling a real antenna. What you radiate, and the rules where you
live, are yours to check.

**There is no output filter in a bare-board build.** The carriers are square
waves, and a square wave at 200 kHz radiates odd harmonics at 600 kHz, 1.0 MHz
and upward, across the whole medium-wave band. For a few minutes on a bench
with a receiver beside it, that is tolerable. For anything left running, fit
the series resistor and low-pass network for each carrier pin, as the Build
Manual describes. Each carrier needs its **own** filter: one filter shared
between both lets them intermodulate.

## 10. When it goes wrong

| What you see | What it is |
| --- | --- |
| `python: command not found` on Windows | Python was installed without **Add python.exe to PATH**. Re-run the installer and tick it |
| `No module named 'tkinter'` | Linux, missing Tk. `sudo apt install python3-tk` |
| No board in the list | Charge-only cable, or the wrong USB socket. See §1 |
| Only the ROM banner, no `amtx>` prompt | You are on the USB-to-serial bridge, not the native port. See §1 |
| Board appears and vanishes repeatedly | Normal for a blank board. Flash it. See §4 |
| `Could not open COM5, the port is busy` | Something else holds the port. Close other terminals. A terminal whose window you closed can leave its process running |
| Nothing selected in the Firmware section | Expected on a release download: there is no `build/` directory. Press **`.bin` file...**. See §5 |
| The flasher cannot catch the board | Put it in download mode by hand: hold BOOT, press and release RESET, release BOOT, then probe again |
| `unrecognised command` from a command in §6 | The firmware on the board is older than this guide. Flash the release binary |
| Typing does nothing in the Monitor tab | Click the lower pane first. See §6 |
| Joined Wi-Fi but `amtx.local` will not open | Use the IP address from `wifi status`. Some networks and some Windows setups do not resolve `.local` names |
| No audio, carrier present | The station URL may be dead. Try `station list`, then `play a <index>` with another, or `discover name jazz` to find one |

### Starting over

To wipe everything saved, including Wi-Fi networks and station changes, and
return the board to how it arrived:

```
amtx> factory-reset confirm
```

## Where to go next

| Manual | For |
| --- | --- |
| User Manual | Driving it: the page, the stations, both transmitters, tuning a receiver |
| Build Manual | Making the real thing: printing the case, winding the antennas, wiring, the output filters |
| Installation Manual | Building the firmware from source, with ESP-IDF |
| Technical Manual | How the firmware works inside, for changing it |

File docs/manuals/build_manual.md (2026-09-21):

# Build Manual

How to build one of these from parts: print the case, wind the antenna, wire
it, flash it, and get it playing. Allow an evening, plus printing time.

It assumes you can solder two joints and use a screwdriver. It does not assume
you have built anything with an ESP32 before.

For using it once it runs, see the User Manual. For how it works inside, see
the Technical Manual. For building the firmware from source rather than
flashing the supplied binary, see the Installation Manual.

## Contents

1. What you need
2. Print the case
3. Fit the heat-set inserts
4. Wind the antenna
5. Wire it up
6. Fit the board
7. Close the box
8. Flash the firmware
9. First boot
10. Check it works
11. Before you transmit
12. If it goes wrong

## 1. What you need

### Parts

| Part | Notes |
| ---- | ----- |
| Waveshare ESP32-S3-Zero | The board this is built around. 24 x 18mm, USB-C. Other ESP32-S3 boards will run the firmware but will not fit the case |
| 2 x 220 ohm resistors | Quarter watt, ordinary carbon or metal film. One per transmitter |
| 0.3mm enamelled copper wire | About 1.5m. Sometimes sold as magnet wire or transformer wire |
| 4 x M3 heat-set inserts | Brass, for 3mm screws, about 4mm outside diameter and 5 to 6mm long |
| 4 x M3 countersunk screws | 8 to 10mm long |
| 2 x M3 self-tapping screws | Short, for the cable clamp. Optional: the clamp is only needed if a cable leaves the box |
| USB-C cable | A data cable, not a charge-only one |
| An AM receiver | Longwave capable for the default 200 kHz, or retune the transmitter to medium wave |

### Tools

A 3D printer and about 40g of PLA. A soldering iron, and a way to melt the
inserts in: a spare iron tip is ideal, the tip of a cheap iron is fine. Snips,
a small screwdriver, fine sandpaper or a scalpel for the enamel.

## 2. Print the case

Three parts: `base`, `lid` and `clamp`. Print each **as supplied and the right
way up**: the models are already in their print orientations, and the whole
design exists to avoid supports.

| Setting | Value |
| --- | ----- |
| Material | PLA |
| Layer height | 0.2mm |
| Infill | 25% |
| Supports | **None.** Nothing in these parts needs them |
| Orientation | As supplied. Do not let the slicer "lay flat" anything |

**Load each part as its own object.** The base and the lid share an origin and
a footprint, and a slicer told to load them as one object will print them
inside each other. That has happened on this project: `PF-01`. If your slicer
offers "load as a single object with multiple parts", do not use it here.
There is also a `sprue` file with all three joined by thin tags, for a printing
service that charges a minimum per part; snap the tags and clean the stubs.

The lid prints outer-face-down, so the lettering ends up on the build plate and
comes out with the plate's finish. The pillars point up.

## 3. Fit the heat-set inserts

Four, one in the foot of each of the lid's pillars. The pillar feet are the
flat-bottomed bosses on what will be the inside of the lid.

1. Set the iron to about 200 C for PLA.
2. Sit an insert, narrow end down, on a pillar foot.
3. Press it in slowly with the iron, square to the surface. It should sink
   under its own weight plus a light push. If you have to lean on it, it is
   too cold.
4. Stop when the insert's top is flush. Let it set before touching it.

Square matters more than speed: a crooked insert means a screw that will not
start, and there is no second attempt in the same hole.

## 4. Wind the antenna

The lid's four pillars are the former. Each pillar has **two channels**
separated by a flange, so the lid carries **two independent windings**, one per
transmitter. Both are **5 turns** of 0.3mm enamelled copper.

1. Start with the lower channel, nearest the lid face. Leave a 100mm tail.
2. Wind 5 turns around all four pillars, keeping the wire in the same channel
   the whole way round. Pull it snug but do not stretch it: the wire runs in
   the 3.5mm gap between the pillars and the wall, and it should sit in the
   channel without bowing.
3. Bring the other end back with another 100mm tail.
4. Repeat in the upper channel for the second winding, leaving two tails again.

The hooks on the long walls hold the wire away from the lid joint. Tuck each
run under them as you go, and the lid will close without trapping anything.

**Leave the tails long.** You can always cut wire off, and the tails have to
reach the resistor uprights and then the board.

Five turns on this former encloses about 15 square centimetres, which is what
was tested and heard on a receiver. More turns is not obviously better: it
raises the inductance and the resistance together.

## 5. Wire it up

One transmitter is: **a GPIO pin, through a 220 ohm resistor, through a 5-turn
winding, back to ground.** There are two of them, and they share only the
ground.

```
GPIO 4 ──── 220R ──── winding A (5 turns) ──── GND
GPIO 5 ──── 220R ──── winding B (5 turns) ──── GND
```

The lid has two pairs of **resistor uprights** near the rear pillars, one pair
per winding. Each pair holds one resistor:

1. Bend both of the resistor's legs square at the shoulders of its body, so
   they point the same way, like a staple.
2. Push the legs into the two bores. They run front to back, towards the back
   stop. The body ends up lying on the lid between the uprights.
3. The legs now stick out towards the back stop, ready to solder to.

Then, per transmitter:

- **Scrape the enamel** off about 8mm of each winding tail. Enamelled wire
  looks like bare copper and is not: if you skip this the joint will look
  perfect and conduct nothing. Sandpaper, a scalpel back, or a hot iron and
  solder will all do it. It is shiny copper when it is clean.
- **Solder one winding tail to one resistor leg.**
- **Solder the other resistor leg to a flying lead** long enough to reach the
  board's GPIO pad, and the other winding tail to a lead for ground.
- Repeat for the second winding and the second resistor.

Finally solder the four leads to the board: **GPIO 4** and **GPIO 5** for the
two transmitters, and both grounds to any **GND** pad. The pads are labelled on
the board's silkscreen.

It does not matter which end of a winding goes to the resistor and which to
ground: it is a loop either way. It does matter that the two windings do not
touch each other, which is what the flange between the channels is for.

## 6. Fit the board

1. **Slide the board in** from the open end, component side up, into the two
   slots along the long walls. It stops against the USB-C wall, with the
   socket lined up with the opening. Nothing clips or springs: if it does not
   slide, something is in the way.
2. **Route the leads.** Four thin wires have to get from the lid to the board.
   They go under the board and through the arch at the foot of the back stop,
   or out sideways through the window each pillar cuts in the slot. Two small
   ribs on the floor under the back of the board hold a cable on the
   centreline so the lid does not sweep it aside as it closes.
3. **If a cable leaves the box**, lay it in the saddle on the lid, put the
   clamp bar over it and fix it with the two self-tapping screws. Weave it
   past the three ledges on the lid and the hooks on the base walls first: the
   point of the weave is that a pull on the cable outside the box is taken by
   the box and not by the solder joints.

## 7. Close the box

Offer the lid up so its four pillars drop into the four corners and the back
stop slides down its guides behind the board. It should sit down without
pressure. **If it does not, stop and look**: a trapped winding tail is the
usual reason, and forcing it is how a pillar snaps.

Turn the whole thing over and drive the four M3 countersunk screws up through
the base floor into the inserts. Snug, not tight: they are pulling brass into
plastic. The heads sit below the underside so the box still stands flat.

## 8. Flash the firmware

Two ways in. Either works; the first needs nothing but Python.

### With the supplied binary

The release carries `amtx-vX.Y-merged.bin`, which is bootloader, partition
table and application in one file at offset 0.

```
pip install esptool
python -m esptool --chip esp32s3 -p COM5 write_flash 0x0 amtx-vX.Y-merged.bin
```

Replace `COM5` with your port: `/dev/ttyACM0` or similar on Linux and macOS.
**Use the board's USB-C socket**, which is the ESP32-S3's own USB: this
firmware puts its console there.

If the board is brand new and keeps dropping off the USB bus while you try,
that is a known trait of a blank ESP32-S3 (`LL-06`). Hold the **B** (BOOT)
button while you plug it in, which forces the ROM's download mode, and flash
then.

### With the graphical flasher

`tools/esp-flasher/esp_flasher.py` finds the board, tells you what is on it,
recommends a full or partial flash and does it, then opens a serial monitor.
`tools/amtx-programmer/amtx_programmer.py` is the same plus a tab that sets the
board up over USB afterwards.

```
pip install -r tools/esp-flasher/requirements.txt
python tools/esp-flasher/esp_flasher.py
```

### From source

See the Installation Manual: ESP-IDF v5.3.x, `idf.py set-target esp32s3`,
`idf.py build`, `idf.py -p PORT flash`.

## 9. First boot

With no saved network the board raises its own access point.

1. Join the Wi-Fi network **`AMTX-Setup`** from a phone or laptop. Give it
   about 30 seconds to appear after power-up.
2. A setup page should open by itself. If not, browse to `http://192.168.4.1`.
3. **Network** tab, **Scan for networks**, pick yours from the list, type the
   password, **Save and join**. Pick from the list rather than typing the name:
   the board has no 5 GHz radio, and a hand-typed 5 GHz name will never join.
4. The board restarts to join, so the setup page disconnects. That is the
   success path, not a failure.
5. Rejoin your own network and open **`http://amtx.local`**. If you have more
   than one of these, give this one its own name on the Network tab.

It comes up playing Radio Swiss Jazz on transmitter A and the BBC World
Service on transmitter B, on 200 kHz and 250 kHz.

## 10. Check it works

Work down the list; each line is something you can see or hear.

| Check | What you should see |
| ----- | --- |
| It has joined | The Network tab shows a state of `connected` and an address |
| It is playing | Now playing shows a station name and `playing`, and the modulation meter moves |
| It is decoding | Diagnostics shows decoded frames climbing, about 40 per second |
| The modulator is fed | Modulator FIFO near half full, underruns not climbing |
| A radio hears it | Tune a receiver to 200 kHz with the loop beside it |

If the receiver hears nothing, check the header says **ON AIR**, then check
your solder joints, then scrape the enamel again. A winding that is not
electrically connected is the most common fault and it looks exactly like one
that is.

If it is distorted, lower the modulation depth, then the programme gain.

## 11. Before you transmit

Three things, none of them optional.

**This is a transmitter in a licensed band.** 200 kHz is inside the longwave
broadcast band, 2 kHz from BBC Radio 4 on 198 kHz. Deliberate radiation there
is licensed in the UK and in most other places, and this project holds no
licence. Keep the field inside the room: the loop is meant to sit beside the
receiver, not to be an antenna.

**There is no filter in this build.** The carrier is a square wave, and a
square wave radiates odd harmonics at 600 kHz, 1.0 MHz and upward, right across
the medium-wave band. The unit described here drives the loop through a single
resistor and nothing else. It works at this power with the receiver in the same
room, and it has never been measured on a spectrum analyser. If you raise the
drive, lengthen the antenna or drop the resistor, the harmonics rise with it
and you should fit the low-pass network in the Technical Manual.

**Give each transmitter its own loop.** Two carriers sharing one output network
intermodulate. This design gives them separate windings for that reason.

## 12. If it goes wrong

| Symptom | Try |
| --- | --- |
| Nothing on the receiver | The enamel. Then the joints. Then that the header says ON AIR |
| The lid will not sit down | A winding tail trapped between a pillar and the wall, or a crooked insert |
| A screw will not start | The insert went in crooked, or the hole is full of melted plastic |
| It will not join the Wi-Fi | 2.4 GHz only. Check the password with the eye button. The console prints the real reason |
| `amtx.local` does not resolve | Some networks do not do mDNS. Use the address from the console's `status` line |
| It is set up wrong and unreachable | Hold the **B** button for five seconds while it runs. It forgets everything and comes back as new |

The serial console answers when the network does not. Connect the USB cable,
open a terminal at any baud rate, press Enter for the `amtx>` prompt, and type
`help`.

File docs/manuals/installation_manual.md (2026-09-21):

# Installation Manual

How to get from a bare ESP32-S3 and a clean machine to a transmitter playing
internet radio. Follow it in order. Each step ends with something you can check.

For day-to-day use once it runs, see the User Manual. For how it works inside,
see the Technical Manual.

## Contents

1. What you need
2. The output network, which is not optional
3. Installing the toolchain
4. Building
5. Flashing
6. First boot and joining a network
7. Checking it works
8. When it goes wrong

## 1. What you need

### Hardware

| Item | Notes |
| ---- | ----- |
| ESP32-S3 board | 8 MB flash. Verified on an ESP32-S3R8, chip revision v0.2, with 8 MB embedded PSRAM |
| USB cable | Data, not charge-only |
| Passives for two output networks | One per carrier. See §2 and Design 03 §4 |
| An AM receiver | Longwave capable if you keep the default 200 kHz carrier |

The board needs no audio hardware, no display and no buttons. Everything is
driven from a web page it serves itself.

Your board may expose two USB ports. One is a USB-to-serial bridge (CH343,
CP210x or similar). The other is the ESP32-S3's own USB peripheral. **Use the
native USB port.** The firmware routes its console there
(`CONFIG_ESP_CONSOLE_USB_SERIAL_JTAG`), so the bridge shows you the ROM
bootloader banner and nothing else. On Windows the native port appears in
Device Manager as `USB JTAG/serial debug unit` with a `USB Serial Device`
COM number.

### Host machine

You need Git, Python 3 and about 4 GB of disk. The ESP-IDF installer fetches
its own compilers, so you do not need a toolchain first.

Windows users: keep the paths short. `C:\esp` works. A deep path under a user
profile can push the build past the Windows path length limit in ways that
report themselves as unrelated compiler errors.

## 2. The output network, which is not optional

Two things stand between this project and a nuisance.

**Fit a low-pass network to each carrier pin.** The carriers are square waves.
A square wave at 200 kHz radiates odd harmonics at 600 kHz, 1.0 MHz, 1.4 MHz
and upward, at a third, a fifth and a seventh of the fundamental. Those land
across the whole medium-wave broadcast band. A bare wire on GPIO 4 splatters
over every station a domestic radio can tune. Design 03 §4 gives a network
that works. This is recorded as `KI-02`.

The firmware runs **two** transmitters, on GPIO 4 and GPIO 5 by default. Each
needs its own network. Coupling both into one lets them intermodulate, and
200 kHz has its third harmonic at 600 kHz, close enough to a second carrier in
the 250 to 300 kHz range that the filtering has to keep them apart rather than
merely tidy each one up. That is `KI-08`.

**Keep the field in the room.** 200 kHz sits inside the longwave broadcast
band, 2 kHz from BBC Radio 4 on 198 kHz. Use an inductive loop under or beside
the receiver, not an antenna. Deliberate radiation in that band is licensed in
the UK and in most other places, and this project holds no licence. What you
actually radiate, and the rules where you live, are yours to check. This is
recorded as `KI-04`.

Neither point is a formality. Build the network before you connect anything to
the pin.

### What the built unit actually has

The as-built wiring

One transmitter per pin: GPIO through a 220 ohm series resistor, into a
five-turn loop, back to the board's ground. **No filter**, which is the
shortcut described in Design 03 §4a and §4b and not a recommendation. It works
at this drive with the receiver in the same room, and nobody has put a
spectrum analyser on it. If you build one with more drive, a longer antenna or
a smaller resistor, fit the network in Design 03 §4.

The transmitter, open

The lid carries both windings and both resistors, and the base carries the
board. The enclosure is `designs/2026-09-tx-case/`.

## 3. Installing the toolchain

The project is pinned to **ESP-IDF v5.3.2**. Other v5.x releases will probably
work and have not been tried.

Clone the SDK. A shallow clone is enough and saves a long wait:

```
git clone --depth 1 --recursive --shallow-submodules \
    -b v5.3.2 https://github.com/espressif/esp-idf.git C:/esp/esp-idf
```

Install the tools for this chip:

```
# Windows PowerShell
$env:IDF_PATH = 'C:\esp\esp-idf'
$env:IDF_TOOLS_PATH = 'C:\esp\tools'
C:\esp\esp-idf\install.ps1 esp32s3
```

```
# macOS and Linux
export IDF_PATH=~/esp/esp-idf
cd $IDF_PATH && ./install.sh esp32s3
```

This downloads roughly 2 GB and takes 15 to 30 minutes. It fetches the Xtensa
and RISC-V compilers, CMake, Ninja, OpenOCD, and builds a Python environment.

**Check:** open a new shell, activate the environment, and ask for a version.

```
# Windows
. C:\esp\esp-idf\export.ps1
# macOS and Linux
. $IDF_PATH/export.sh

idf.py --version        # should print ESP-IDF v5.3.2
```

The environment is per-shell. Run `export` again in every new terminal. This is
the single most common cause of `idf.py: command not found`.

## 4. Building

From the repository root:

```
idf.py set-target esp32s3
idf.py build
```

The first build resolves two managed components from the Espressif registry,
`chmorgan/esp-libhelix-mp3` and `espressif/mdns`, then compiles about a
thousand files. Allow several minutes. Later builds take seconds.

**Check:** the build ends with a size line and no warnings.

```
amtx.bin binary size 0x11c0b0 bytes. Smallest app partition is 0x300000 bytes.
0x1e3f50 bytes (63%) free.
Project build complete.
```

You do not need `idf.py menuconfig`. Everything it sets has a working default,
and Wi-Fi is configured from the board itself. Use it only to change the RF
pin, the audio low-pass, or the two stations a fresh board starts on (Radio
Swiss Jazz on A, BBC World Service on B). Anything you enter there
lands in `sdkconfig`, which is deliberately not tracked by Git because it can
hold a Wi-Fi password.

### Host-side tests, no hardware needed

The audio maths builds and runs on your machine:

```
make -C test/host test
```

Twenty-seven checks covering the filters, the resampler, the limiter and the
arcsine duty table. They should all pass. On Windows with MinGW, use
`mingw32-make CC=gcc`.

## 5. Flashing

Find the port. On Windows it is the `USB Serial Device` COM number that appears
when you connect the native USB port. On Linux it is usually `/dev/ttyACM0`, on
macOS `/dev/cu.usbmodem*`.

```
idf.py -p COM18 flash
```

Each of the three images ends with `Hash of data verified`.

**Or use the flasher.** `python tools/esp-flasher/esp_flasher.py` finds the
board, reads what is on it, writes the bootloader, partition table and app from
`build/` (or only the app, when the rest already matches), and opens a serial
monitor on the board afterwards. It needs no ESP-IDF shell, only
`pip install -r tools/esp-flasher/requirements.txt`. See its `README.md`.

**A new board that keeps disappearing.** A blank ESP32-S3 resets every couple
of seconds and drops off USB each time (`LL-06`). The flasher catches it
anyway. With `idf.py`, hold BOOT, press and release RESET, release BOOT, then
flash: the board stays put in download mode.

**If the port is busy:** close anything else holding it. A serial terminal
keeps the port open, and Windows will not share it. The error is
`Could not open COM18, the port is busy or doesn't exist`. Note that a terminal
whose window you closed can leave its process running and still holding the
port.

## 6. First boot and joining a network

With no saved network, the board raises its own open access point.

1. Look for a Wi-Fi network called **AMTX-Setup** and join it. It takes about
   30 seconds to appear after a reset.
2. A setup page should open by itself. If it does not, browse to
   `http://192.168.4.1`.
3. Open the **Network** tab and press **Scan for networks**.
4. Pick your network from the list. Using the list rather than typing the name
   matters: the scan only returns 2.4 GHz networks, and the ESP32-S3 has no
   5 GHz radio, so a hand-typed 5 GHz name will never join.
5. Type the password. Press the eye button beside the field to check it before
   you commit.
6. Press **Save and join**.

A dialog tells you the board is restarting to join. **The setup portal will
disconnect at this point, and that is the success path**, not a failure: the
access point has to come down before the board can join your network.

**Or do it over the USB cable instead.** `python
tools/amtx-programmer/amtx_programmer.py` finds the board, opens its console
and gives you the same settings as buttons and dialogs: networks, stations,
both transmitters, the hostname and the web interface. It is the only route in
once the web interface has been turned off, and it needs no phone.

Reconnect your phone or laptop to your own network and open `http://amtx.local`.
If another transmitter on the network already answers to that name, set this
one's hostname on the Network tab, or with `hostname <name>` on the serial
console, and use `http://<name>.local` from then on.

If the password was wrong, the board gives up after about 15 seconds per saved
network and brings `AMTX-Setup` back, so you can rejoin and try again.

### If mDNS does not work

Some networks and some operating systems do not resolve `.local` names. Find
the address instead. Connect the native USB port, open a serial terminal at
115200 baud, and wait up to 30 seconds:

```
I (30300) wifi: wifi up: connected to "YourNetwork", ip 192.168.0.123, rssi -57 dBm, drops 0
```

That heartbeat prints every 30 seconds whether or not anything has changed, so
silence means nothing is running rather than nothing has changed.

You can also ask the board directly. Press Enter in the terminal to get the
`amtx>` prompt and type `status`.

## 7. Checking it works

Work down this list. Each line is something you can see.

| Check | What you should see |
| ----- | --- |
| It boots | `webui: web interface up on port 80` |
| It joined | `wifi up: connected to "...", ip ...` every 30 s |
| The web UI answers | `http://amtx.local` loads the page |
| The carrier runs | Header reads `ON AIR 200.0 kHz 70%` |
| A stream plays | Now playing shows a station and `playing` |
| Audio decodes | Diagnostics shows decoded frames climbing, roughly 40 per second |
| The modulator is fed | Modulator FIFO near half full, underruns not climbing |
| A radio hears it | Tune the receiver to the carrier frequency |

The last line is the only one this project has never checked. Nothing here has
been measured off-air: no receiver, no spectrum analyser, no field-strength
reading. The signal chain is verified up to the duty register and no further.

### If it is set up wrong and you cannot reach it

Hold the board's **BOOT** button (marked **B**) for five seconds while it is
running. It forgets every station, every saved network, both transmitters'
settings, its hostname and whether the web interface runs, then restarts and
raises `AMTX-Setup` again. The firmware stays; this only clears what the board
remembers. User Manual §6 has the detail.

That is the answer to the two states nothing else recovers: a board whose only
saved network no longer exists, and a board whose web interface was turned off
on a network you can no longer join.

## 8. When it goes wrong

**`idf.py` not found.** The environment is per-shell. Run the export script
again.

**Build fails on a missing component.** The first build needs to reach
`components.espressif.com`. Behind a restrictive proxy it cannot, and the error
does not say so. `LL-03` records the workaround.

**Nothing on the serial port but a ROM banner.** You are on the USB-to-serial
bridge, not the native USB port. Move the cable.

**The port is busy.** Something else has it open. See §5.

**The port keeps appearing and vanishing.** The flash is blank or corrupt and
the chip is boot-looping. Flash it; see §5 and `LL-06`.

**The setup portal will not take a password.** Firmware before the `KI-07` fix
reset itself on every settings write, so no credential could ever be saved.
Check you are running a current build. The symptom is a board that joins your
network correctly and then reappears on `AMTX-Setup` after a reboot with
nothing saved.

**A station will not play.** Check Diagnostics for the HTTP status. `302` on a
current build means the redirect chain ran past its limit. Anything that is
not MP3 will connect and then produce silence, because libhelix is the only
decoder compiled in.

**Your browser keeps probing.** While you sit on `AMTX-Setup`, phones and
browsers poll for a captive portal every few seconds. That is normal and stops
once the board has real internet.

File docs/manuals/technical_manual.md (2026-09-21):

# Technical Manual

How the firmware works, for someone about to change it. The design documents
in `docs/design/` carry the reasoning behind each decision; this manual is the
working reference that sits above them.

For building and flashing, see the Installation Manual. For operating it, see
the User Manual.

## Contents

1. The signal chain
2. Why duty-cycle AM needs an arcsine table
3. Tasks, cores and the real-time contract
4. Module map
5. Storage
6. HTTP API
7. Serial console
8. Memory
9. Traps that have already been paid for
10. Limits and what would lift them

## 1. The signal chain

There are two of these, indexed 0 and 1, and they are independent
transmitters. Each has its own station, carrier frequency, modulation depth,
audio low-pass, gain, output pin and power-on default. They share one Wi-Fi
connection, one station list, one modulation timer and the 80 MHz LEDC clock.

```
Wi-Fi -> HTTP MP3 -> 64 kB ring buffer -> libhelix -> mono -> DC block
      -> 6-pole low-pass at 4.5 kHz -> resample to 20 kHz -> limiter
      -> lockless FIFO -> 20 kHz IRAM ISR -> arcsine table
      -> LEDC duty register -> GPIO 4 -> low-pass network -> loop   [chain 0]
                                      -> GPIO 5 -> its own network  [chain 1]
```

The ring buffers live in PSRAM; everything the ISR touches stays in internal
DRAM. Each chain runs its own resampler trim loop, because two stations drift
against this board's crystal independently.

Each stage exists for a reason.

**Ring buffer.** 64 kB of raw MP3, about four seconds at 128 kbit/s. Absorbs
network jitter so the decoder never starves on a slow TCP window.

**Mono downmix.** The carrier has one envelope. Two channels are averaged with
headroom so full-scale correlated material cannot wrap.

**DC block.** A one-pole high-pass at 25 Hz. MP3 decoders emit a DC offset on
some material, and DC here shifts the carrier bias rather than being inaudible.

**Low-pass.** Three cascaded biquads, a 6th-order Butterworth at 4.5 kHz. It
is 41 dB down at 10 kHz where a 2nd-order design manages 14 dB. This is what
keeps the transmission inside a 9 kHz channel.

**Resampler.** Linear interpolation from the stream rate to 20 kHz. It also
nudges its own step to hold the sample FIFO near half full, absorbing the drift
between the station's clock and this board's crystal. Without that the FIFO
walks to one end and clicks every few minutes. The correction is bounded at
5000 ppm, far more than two crystals can differ and small enough to be
inaudible.

**AGC.** Between the fixed gain and the limiter. Tracks programme RMS and
drives gain towards a target, because stations differ by more than 10 dB in
average level and a peak limiter cannot close that gap: it only pushes peaks
down. Asymmetric slew, 200 ms down and 3 s up, bounded -6/+18 dB, gated at
-50 dBFS so speech pauses do not lift the noise floor. See `EH-11`.

**Limiter.** 1 ms attack, 250 ms release, ceiling at 0.95 of full scale. Last
in the chain, as the safety net: the AGC targets an average, and peaks are not
its job.

**FIFO.** 2048 samples, 102 ms at 20 kHz. Single producer, single consumer,
lockless. The decode task writes the head, the ISR writes the tail, and neither
touches the other's index. This is why the decode task and the ISR must share
a core.

## 2. Why duty-cycle AM needs an arcsine table

This is the part of the design worth understanding before changing anything.

The amplitude a square wave radiates at its own frequency goes as `sin(pi*D)`,
where `D` is the duty cycle. That function **peaks** at 50% duty, so its slope
there is zero. Modulating duty about 50%, which is the obvious reading of the
brief, produces almost no amplitude modulation. Swinging from 25% to 75% moves
the radiated amplitude from 0.707 to 0.707.

So the firmware puts the modulation **peak** at 50% duty, sits the unmodulated
carrier at `1/(1+m)` of it, and inverts the sine into a 512-entry table built
once at configuration time:

```
D = asin(a) / pi
```

The interrupt is then a lookup, an add, a clamp and a register write. The
envelope comes out linear in the sample.

For the default depth of 0.70 the quiescent duty is `asin(1/1.70)/pi = 0.2002`,
which lands on 51 of 256 register steps. Seeing `quiescent duty 51/256` in the
boot log is confirmation the table built correctly.

This is `KI-01` and `LL-02`. The host test suite asserts it, including a check
that the brief's original 50%-centred scheme really is flat.

### Noise shaping

At 200 kHz on the 80 MHz LEDC clock there are 400 clocks per period, so the
duty register has 8 usable bits. Around the bias point that leaves roughly
6.5 bits of amplitude resolution. First-order error feedback on the duty
quantiser carries the rounding error into the next tick, which pushes most of
that noise above the 4.5 kHz audio band. Two adds in the ISR. Set
`RF_NOISE_SHAPING` to 0 to compare on a scope.

None of this has been measured on hardware.

## 3. Tasks, cores and the real-time contract

| Task | Core | Priority | Stack | Count |
| ---- | ---- | --- | ----- | ----- |
| Modulation ISR | 1 | interrupt | n/a | 1, serving every chain |
| Decode | 1 | 10 | 12288 | one per chain |
| Stream | 0 | 5 | 8192 | one per chain |
| Wi-Fi, lwIP, httpd | 0 | IDF defaults | IDF defaults | 1 |
| Console REPL | 0 | IDF default | 4096 | 1 |

Measured with two chains playing different stations **on an ESP32-S3R8, the
module with 8 MB octal PSRAM**: each decoder sustains 42.1 frames/s, which is
the correct rate for 48 kHz MP3, with modulator underruns static and both FIFOs
near full. Core 1 carries two decoders and the 20 kHz ISR without strain.

**A quad-PSRAM module does it too.** Measured on a Waveshare ESP32-S3-Zero
(2 MB quad PSRAM) on 2026-09-18: two 48 kHz 128 kbit/s streams at once, 41.8
and 41.8 frames/s, zero underruns, on both the pre-refactor build and the
refactored one. The same board had been seen running 21% slow on both chains
shortly after a flash, which is `KI-14`: unexplained, not reproducible since,
and left open rather than explained away.

The ISR's own cost has never been measured directly, and `WI-1`'s decode-cost
measurement is still outstanding. **Know which module you have** before
trusting either set of numbers.

The split is not arbitrary. Core 0 carries everything that can block on the
network. Core 1 carries the audio path and nothing else, so no decode ever
waits on a socket.

Three rules hold the real-time behaviour together.

**The modulation ISR must not touch flash.** It is `IRAM_ATTR`, its tables are
`DRAM_ATTR`, and `sdkconfig.defaults` sets `CONFIG_GPTIMER_ISR_IRAM_SAFE`,
`CONFIG_GPTIMER_CTRL_FUNC_IN_IRAM` and `CONFIG_GPTIMER_ISR_HANDLER_IN_IRAM`.
Without those the ISR lives in flash and the first cache miss during an SPI
flash operation takes the carrier with it.

**The ISR must be registered from core 1.** A gptimer ISR is allocated on the
core that registers it, so `app_init()` runs from a task pinned to
`TASK_CORE_AUDIO`, not from `app_main()`. See `main.c`. Every decode task is
pinned there too, for the same FIFO reason.

**Stop the ISR across a flash write.** Being IRAM-safe is necessary but not
sufficient. Taking a 20 kHz interrupt continuously through a cache-disabled
window starves the interrupt watchdog and the board resets before the write
lands. `carrier_suspend()` and `carrier_resume()` bracket every `nvs_commit()`.
This is `KI-07` and §9 covers what it cost to find.

## 4. Module map

| File | Responsibility |
| ---- | --- |
| `main.c` | Bring-up order, and nothing else |
| `app.c` | Glue: what plays, what the RF settings are |
| `state_doc.c` | The state document, for `/api/state` and the console's `state` |
| `audio/decoder.c` | libhelix, the DSP chain, the test tone |
| `audio/dsp.c` | Filters, resampler, limiter, duty table. Host-testable |
| `audio/sample_fifo.h` | The lockless FIFO |
| `net/stream.c` | HTTP fetch into the ring buffer, retry and backoff |
| `net/wifi_conn.c` | Joining, the setup portal, the captive DNS, the heartbeat |
| `net/discover.c` | Radio-Browser search |
| `net/webui.c` | HTTP server and the JSON API |
| `net/www_page.h` | The whole UI. Assembles the three below, and what is served is their concatenation byte for byte |
| `net/www_style.h`, `www_body.h`, `www_script.h` | The stylesheet, the markup, the script |
| `rf/carrier.c` | LEDC, the gptimer, the modulation ISR |
| `button.c` | The BOOT button, and the factory reset a five-second hold triggers |
| `cli/console.c` | The REPL, and the one loop that registers every command |
| `cli/cli_reply.c` | The `ok` / `error:` convention and the shared argument parsers |
| `cli/cmd_radio.c` | play, stop, station, rf, tone, discover |
| `cli/cmd_net.c` | wifi, hostname, web |
| `cli/cmd_system.c` | status, state, log, reboot |
| `store/settings.c` | Mounting NVS and the load order. `settings.h` is the one public header |
| `store/settings_stations.c` | The `radio` namespace: the station list and the indices into it |
| `store/settings_wifi.c` | The `wifi` namespace: saved credentials |
| `store/settings_rf.c` | The `rf` namespace: per-transmitter carrier and audio settings |
| `store/settings_sys.c` | The `sys` namespace: hostname, and whether the web runs |
| `store/settings_internal.h` | What those four share, including the carrier bracket every NVS write needs (`KI-07`) |

**Two seams worth knowing before you change anything here.** The command
groups under `cli/` each publish a table and `console.c` registers all of them
in one loop, so a command lives with its neighbours rather than in one long
file; what any of them prints is a contract (design 07 §2) that the programmer
tool parses, so moving a command is free and rewording its reply is not. And
`store/` is split one file per NVS namespace, matching the schema in design 04
§4: each owns its own RAM cache, its own save path and its own defaults, and
none of them reads another's.

`audio/dsp.c` is deliberately free of ESP-IDF headers so it compiles on a host.
`test/host/` builds it with the test suite. If a change to `dsp.c` breaks that
build, the change is at fault, not the test.

## 5. Storage

Four NVS namespaces, one file each under `store/`. Keys are 15 characters or
fewer, as NVS requires. Design 04 holds the schema table, and a new key is a
change to that table in the same commit.

| Namespace | Keys | Holds |
| --- | ---- | ----- |
| `radio` | `cnt`, `last`, `def`, `na0..n`, `ur0..n`, `tr0..n` | Station list, last played, power-on default, per-station trim |
| `wifi` | `n`, `s0..n`, `p0..n` | Credentials, newest first |
| `rf` | `on`, `hz`, `depth`, `lpf`, `gain`, `lvl`, `agc`, `agct`, `fdm`, `fdr`, `fdd`, and the same suffixed `1` for the second transmitter | Transmitter settings |
| `sys` | `host`, `web` | The hostname, and whether the web interface runs |

Stations and credentials are cached in RAM and written through, so a web
handler never blocks on flash while holding anything.

### Indices name a station, not a position

`last` and `def` are both indices into the station list. Any operation that
renumbers the list has to carry them along, or reordering silently changes
which station the board wakes up on.

`settings_station_move()` remaps both through `remap_after_move()`.
`settings_station_delete()` decrements them past the gap, and clears `def`
outright if the starred station is the one deleted, because a default nobody
chose is worse than none.

`def` is -1 when unset, in which case boot falls back to `last`.

## 6. HTTP API

Everything is JSON. Design 04 §3 is the contract.

| Method | Path | Body | Returns |
| --- | ---- | ---- | --- |
| GET | `/` | | The page |
| GET | `/api/state` | | Everything. Polled once a second |
| GET | `/api/wifi/scan` | | `[{ssid, rssi, secure}]`. Blocking |
| GET | `/api/discover` | `?q=` `&by=name\|tag\|country` | `[{name, url, country, codec, bitrate, votes}]` or `{error}` |
| POST | `/api/station/play` | `{index}` or `{url}` | `{ok}` |
| POST | `/api/station/add` | `{name, url}` | `{ok}` |
| POST | `/api/station/delete` | `{index}` | `{ok}` |
| POST | `/api/station/move` | `{from, to}` | `{ok}` |
| POST | `/api/station/default` | `{index}`, negative to clear | `{ok}` |
| POST | `/api/stop` | `{}` | `{ok}` |
| POST | `/api/rf` | `{on, hz, depth, lpf, gain}` | `{ok}` |
| POST | `/api/tone` | `{on, hz}` | `{ok}` |
| POST | `/api/wifi/add` | `{ssid, pass}` | `{ok}`, then reboots if from the portal |
| POST | `/api/reboot` | `{}` | `{ok}` |
| POST | `/api/hostname` | `{host}` | `{ok}` |
| POST | `/api/web` | `{on: false}` | `{ok}`, then the server stops |

Every POST answers `{"ok":bool}` and, on failure, `{"error":"ESP_ERR_..."}`.
The page shows that string to the operator rather than swallowing it.

`station/move` performs a splice, not a swap, which is exactly drag-and-drop
semantics. The UI reuses it for both the arrows and the drag.

A 404 redirects to `/`, which is what makes the captive portal open by itself.
Captive-portal probes are frequent enough that the `httpd_uri` log tag is
turned down to `ERROR`, or their warnings bury everything else.

## 7. Serial console

An `esp_console` REPL on the USB Serial JTAG peripheral, started before
`wifi_conn_start()`, which blocks, so the console answers while join attempts
are still running.

`cli/console.c` holds the REPL and the registration loop; the commands
themselves are grouped in `cmd_radio.c`, `cmd_net.c` and `cmd_system.c`, and
the reply convention and the argument parsers are in `cli_reply.c`. The
grouping is for the reader: `esp_console` sorts its own command list, so
nothing a program sees depends on which file a command lives in.

It reaches every function the page does, and design 07 §2 is its reference.
Commands added with it end with one `ok` or `error:` line and return 0,
because a non-zero return makes the REPL print a line of its own after the
reply. `discover` runs its search on a 6 kB task created for the search,
because the TLS handshake does not fit the REPL's 4 kB stack and a bigger
stack would hold internal RAM permanently (`LL-07`).

`log off` sets the global log level to `NONE` so `status` can be polled by a
script. `log on` restores `INFO` and re-applies the `httpd_uri` suppression.
The quiet mode is not persisted: logging is on after every boot.

`status` prints one line, fixed field order:

```
state=connected ssid="..." ip=... rssi=-55 drops=0 saved=1 heap=... heapint=...
heapintmax=... uptime=134 carrier0=on hz0=200000 depth0=70 playing0=1
underruns0=0 carrier1=on ... host=amtx web=on
```

(One line on the board; wrapped here.)

## 8. Memory

Roughly 8 MB of heap free at rest. **That number is close to meaningless**,
and watching it instead of internal RAM cost a debugging session (`LL-07`).

The figure that constrains this board is internal DRAM, and there is about
19 kB of it free with two chains playing. Everything scarce competes for it:
Wi-Fi buffers, DMA, task stacks and mbedTLS. Both the Diagnostics page and the
CLI `status` line report internal free and its largest free block for exactly
this reason.

| Consumer | Size | Where |
| --- | ---- | ----- |
| Stream ring buffer | 64 kB each, 128 kB total | PSRAM |
| Decoder working buffers | 15 kB each, 30 kB total | PSRAM |
| Sample FIFO | 4 kB each, 8 kB total | Internal, and must stay there |
| Duty table | 1 kB each | Internal, and must stay there |
| Discovery reply buffer | 20 kB, transient | PSRAM |
| mbedTLS session | Tens of kB, transient | PSRAM, via `CONFIG_MBEDTLS_EXTERNAL_MEM_ALLOC` |
| PSRAM DMA reserve | 32 kB | Internal, reserved by IDF |

The two rows marked "must stay there" are the modulation ISR's, and PSRAM is
reached over SPI. Nothing on that path may live in it.

PSRAM is **on**. The module is an **ESP32-S3R8 with 8 MB octal PSRAM**, which
answers Design 06 §2.1, and `sdkconfig.defaults` sets `CONFIG_SPIRAM_MODE_OCT`.
The stream ring buffer moves there by itself, because `stream_init()` asks for
PSRAM first and falls back.

Nothing on the real-time path lives in PSRAM. It is reached over SPI, so it
must never be in the modulation ISR's way: the ISR stays `IRAM_ATTR` and its
tables `DRAM_ATTR`, exactly as before.

`CONFIG_SPIRAM_IGNORE_NOTFOUND` keeps a board without PSRAM booting rather than
failing at startup, so the default stays safe on other modules.

The tight spot is a TLS handshake. mbedTLS with the full certificate bundle
takes the largest contiguous block while it runs, so an allocation attempted
after the handshake can fail with 99 kB apparently free. `discover.c` claims
its reply buffer before opening the connection for exactly this reason.

## 9. Traps that have already been paid for

Read this section before spending a day on any of them again.

**`KI-07`: an NVS write with the modulator running resets the board.** See §3.
It presented as a Wi-Fi fault for a whole session, because the setup portal is
where you first try to save something. `settings_set_last_station()` hid it
further by returning early when the index has not changed, so an ordinary boot
performs no real flash write and never trips it.

**`LL-04`: `max_redirection_count` does nothing on the `open()` path.**
`esp_http_client` follows redirects only inside `esp_http_client_perform()`. A
stream cannot use `perform()`, so it uses `open()` and `fetch_headers()`, and
the config field is never consulted. Follow them by hand: close, then
`esp_http_client_set_redirection()`, then open again.

**`KI-05`: Shoutcast v1 answers `ICY 200 OK`.** That is not a status line
`esp_http_client` can parse. Presenting a browser User-Agent gets a normal
response.

**TLS was compiled in all along.** The UI carried a "TLS is not compiled in"
warning for a long time. It was wrong. `CONFIG_ESP_HTTP_CLIENT_ENABLE_HTTPS`
and the full certificate bundle were both set. What was missing was
`crt_bundle_attach` on the stream client, which is a different problem with the
same symptom, and the wrong note discouraged anyone from looking.

**The console goes to the native USB port.** `CONFIG_ESP_CONSOLE_USB_SERIAL_JTAG`
means a USB-to-serial bridge on the same board shows you the ROM banner and
nothing more. A panic would be equally invisible there.

## 10. Limits and what would lift them

| Limit | Cause | What would lift it |
| ----- | ----- | --- |
| MP3 only | libhelix is the only decoder | `EH-04` |
| 10 discovery results | Internal heap during a TLS handshake. PSRAM is now on, so this could be raised and has not been retested | Raise `DISCOVER_RESULTS_MAX` |
| 20 stations | `STATION_MAX` | Raise it. NVS has room |
| Carrier below roughly 300 kHz | 8-bit duty on an 80 MHz LEDC clock | Fewer duty bits, at a cost in resolution |
| 6.5 bits of amplitude resolution | Same | `EH-05`, a faster modulation rate |
| No stream metadata | ICY is interleaved and not stripped | `EH-08` |
| Fading is a table rebuild | Level is baked into the duty table | Index the table by amplitude instead, making level a runtime multiply |
| No authentication | Not implemented | `KI-06` |
| Harmonics across medium wave | A square wave carrier | An output network. `KI-02`. Not fixable in firmware |

### What has never been verified

The firmware runs. The audio chain is tested on a host and observed working on
hardware, from an internet stream through to the duty register.

Nothing has been measured off-air. There has been no receiver, no scope and no
spectrum analyser on this project at any point. The RF behaviour, the harmonic
content, the modulation quality and the actual radiated field are all
unobserved. Design 06 lists what else was assumed.

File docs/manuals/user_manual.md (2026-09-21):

# User Manual

Everything you can do with the transmitter once it is built and on your
network. To get to that point, see the Installation Manual.

The board has no display, no buttons and no knobs. You drive all of it from a
web page it serves itself, at `http://amtx.local` or at its IP address, or
from the serial console, which can do everything the page can.

## Contents

1. The page at a glance
2. Now playing
3. Stations
4. Discover
5. Transmitter
6. Network
7. Diagnostics
8. Tuning a receiver
9. The serial console
10. Before you transmit

The transmitter, open

The built transmitter: the lid carries the two loop windings and their series
resistors, the base carries the board. `docs/images/wiring.svg` is what is
wired to what.

## 1. The page at a glance

There are **two independent transmitters**, A and B. Each plays its own
station on its own carrier frequency, out of its own pin, with its own
modulation settings. They share your station list and your Wi-Fi.

Six tabs across the top, and a header that always shows both carriers.

```
A ON AIR 200.0 kHz 70%    B ON AIR 250.0 kHz 70%
```

Amber is A, blue is B. Grey and reading `OFF` means that carrier is not
running. The numbers are the carrier frequency and the modulation depth.

Below the tabs is an **Acting on** bar with two buttons. Whichever transmitter
is selected there is the one the Stations, Discover and Transmitter tabs act
on. Now playing and Diagnostics always show both, because what is on air is
the question you want answered without clicking anything.

Every button reports back. Press one and it indents, then a message slides up
from the bottom of the screen telling you what happened. A red message means
the transmitter refused, and it says why. This matters more than it sounds:
with no display on the board, that message is the only confirmation you get
that a press did anything at all.

Two actions restart the board, so they raise a dialog you have to dismiss
rather than a message that fades. Both are on the Network tab.

## 2. Now playing

The station name, its URL, and a **Modulation** meter.

The meter shows the peak level going into the modulator. Green is normal.
Amber above 80% means you are running hot. Red above 97% means the limiter is
working hard and the sound will suffer. If it sits red, lower the programme
gain on the Transmitter tab.

One card per transmitter, each with its own controls.

**Stop** stops that transmitter's audio. Its carrier stays up, unmodulated, so
a receiver tuned to it hears silence rather than losing the station. The other
transmitter is untouched.

**Carrier** switches that output on and off. The button says what pressing it
will do.

**Play a URL directly** takes any HTTP MP3 stream address and plays it without
saving it. Use it to try a station before you keep it.

## 3. Stations

Your saved list, up to 20 stations.

Each row has a drag grip, the name and URL, and five controls.

| Control | What it does |
| --- | --- |
| ★ | Makes this the station the transmitter plays at power-on |
| Play | Tune to it now |
| % | Level trim for this station, 10 to 400%. For when the AGC gets one wrong |
| ↑ ↓ | Move it one place |
| × | Delete it |

### Ordering

Drag a row by any part of it and drop it where you want it. The order is saved
as you go, so it survives a power cut.

The arrows do the same job. Keep them in mind on a phone or tablet, where
dragging does not work: HTML5 drag-and-drop is a mouse feature and touch
browsers do not implement it.

### The power-on station

Press the star on a row and that station becomes the one **the selected
transmitter** tunes when it powers up. The star turns amber. Press it again to
clear it.

Each transmitter has its own star. Switch between A and B on the Acting on bar
and the stars change to show that transmitter's choice, so you can have A come
up on one station and B on another.

With no star set, the board comes back on whatever it was playing when it lost
power. With a star set, it always comes back on that station, whatever was
playing before.

The star follows its station when you reorder the list. Drag the starred
station from the bottom to the top and it stays starred. Delete the starred
station and the star clears rather than jumping to a neighbour, because a
default nobody chose is worse than none.

### Adding by hand

Type a name and a stream URL and press **Add**. The URL must be plain HTTP or
HTTPS to an MP3 stream. Playlist files (`.pls`, `.m3u`) are not parsed, and
HLS streams (`.m3u8`) will connect and then stop, because the firmware expects
a continuous MP3 byte stream.

## 4. Discover

Search a community directory of internet radio stations rather than hunting
for URLs yourself.

Type something, choose whether it searches by name, genre or country, and
press **Search**. Results come back ordered by how many people listen to them.
Each row offers:

- **Play**, which tunes to it now without saving.
- **Save**, which adds it to the end of your station list.

Results are limited to ten. That was a memory limit: a secure connection to
the directory takes tens of kB while it runs, and each result is roughly
1.5 kB of data, which once exhausted the internal RAM. PSRAM is enabled now,
so the limit could probably be raised, but it has not been retested and the
cap still stands. Narrow the search rather than expecting more rows.

Two filters are applied for you, and both reflect what the firmware can
actually play:

- **MP3 only.** It is the only decoder compiled in. An AAC or OGG station
  would save cleanly and then play silence.
- **Plain HTTP only.** Encrypted streams are filtered out at the directory.

## 5. Transmitter

The RF settings. Press **Apply and save** to commit them. They persist.

| Setting | Range | What it does |
| --- | ----- | --- |
| Carrier | 60 to 300 kHz | The frequency you tune the receiver to |
| Modulation depth | 5 to 90% | How far the envelope swings |
| Audio low-pass | 500 to 9500 Hz | Where the audio is cut off |
| Programme gain | 0 to 400% | Level into the limiter |
| Carrier output | On or off | The output itself |

These act on the transmitter selected in the Acting on bar. The panel border
shows which: amber for A, blue for B.

**Carrier.** A defaults to 200 kHz and B to 250 kHz, both in the longwave
band. Not every frequency you type will be accepted. The hardware divides an
80 MHz clock and needs 256 duty steps per cycle, so **312.5 kHz is a hard
ceiling** and the medium-wave band is out of reach at this duty resolution.
Ask for 800 kHz or 1.2 MHz and the transmitter refuses and keeps the frequency
it had. The message tells you.

Keep the two carriers apart, and mind the harmonics: 200 kHz has its third
harmonic at 600 kHz, so a second carrier is not the only thing sharing the
air with the first.

**Modulation depth.** 70% is a good starting point. Above 75% the trough
pinches the carrier and an envelope detector, which is what a cheap AM radio
is, turns that into distortion. The setting allows more so you can hear the
effect. It is not an improvement.

**Audio low-pass.** 4500 Hz keeps the transmission inside a 9 kHz channel.
Raising it makes the audio brighter and puts energy into the next channel
along, where it becomes someone else's problem.

**Programme gain.** Broadcast AM runs hot, and 140% is the default for that
reason. Watch the modulation meter on the Now playing tab. If it sits red,
come down.

**Carrier level.** How hard the transmitter drives, 5 to 100%. This is the
honest way to turn the power down: it shrinks the whole radiated envelope,
rather than turning the audio down and leaving the carrier at full strength.
It costs resolution, because the envelope then uses fewer duty steps, so at
25% there is a quarter of the amplitude resolution there was at 100%. Use it
to keep the field small; use programme gain and the AGC to control loudness.

### Loudness AGC

Stations differ by more than 10 dB in average level. Measured on this board:
Jazz Blues averaged 0.738 while Radio Swiss Jazz averaged 0.213, on identical
settings. A compressed music service runs near full scale, a jazz service with
real dynamic range averages far lower, and speech with pauses lower still.

The limiter cannot fix that, because a limiter only pushes peaks down and never
lifts quiet material up. The AGC tracks the programme average and rides the
gain to a target, which is what broadcast AM processing does and why AM
stations all sound equally loud. With it on, those two stations came to within
1.9 dB of each other.

It shows what it is doing beside the switch, as a gain in dB.

**Target level** is what it aims the average at. 25% is a good default. Higher
is louder and closer to the limiter.

It trades dynamic range for loudness, which is the same bargain every
broadcaster makes. Switch it off per transmitter if you would rather keep the
dynamics. For the odd station it gets wrong, use the per-station trim: the
percentage button on the station row.

### Fading

For fun, and for realism. Wanders the carrier level so the signal comes and
goes the way a distant station does. It acts on the carrier rather than the
audio, so the noise floor rises and falls with it, exactly as propagation
does.

| Mode | What it sounds like |
| ---- | --- |
| Slow fade | Long, lazy fades. Try 0.05 to 0.2 Hz |
| Flutter | Faster wobble. Aircraft flutter, aurora. Try 3 to 10 Hz |
| Random drift | Three unrelated rates summed, so it never repeats. The most convincing |

**Rate** sets the speed and **Depth** how far down it dips. 100% depth takes
the carrier to nothing at the bottom of the fade.

It costs nothing when off.

### Test tone

Replaces the programme with a steady tone at the modulator's own rate. Put a
scope on the RF pin and you see the envelope with the decoder and the network
taken out of the picture. Useful for checking the output stage without
wondering whether the stream is at fault.

## 6. Network

The top panel shows the state, the network, the address, the signal strength
and how many times the connection has dropped.

**Scan for networks** lists what the board can see, with signal strengths.
Press **Use** on one to fill in the name. Only 2.4 GHz networks appear, because
that is all the radio has.

**Password** has an eye button beside it. Press it to read what you typed
before you commit, which saves a reboot cycle spent wondering.

**Save and join** stores the credentials and restarts to join. The page will
lose contact. That is expected, and the dialog says so.

**Reboot** restarts the transmitter.

**Hostname** is the name the board answers to, `http://<name>.local`. Every
board starts as `amtx`, so with two on one network, give each its own name or
only one of them answers. Letters, digits and hyphens, up to 31. The new name
works at once; the router's device list shows it after a reboot.

**Turn off the web interface** stops this page altogether, for a network you
do not trust: the page has no password. It asks first, because the page
cannot turn itself back on. Only the serial console can, with `web on`, and
while the web is off there is no setup portal either.

On a phone held upright a banner asks you to turn it sideways. The page works
upright, but it is laid out for landscape. Dismiss the banner with its ×.

### Starting again from nothing

**Hold the board's BOOT button for five seconds** while it is running. The
button is marked **B**; the other one, **R**, is RESET and cannot do this.

The transmission stops, and the board restarts as if it were new: no stations
but the two it was built with, no saved networks, default transmitter
settings, the name `amtx`, and the web interface back on. Then it raises the
`AMTX-Setup` access point and waits to be set up again, as in the Installation
Manual §6.

Let go before five seconds and nothing happens at all. If the serial console
is connected it counts down while you hold it.

The same thing, from further away:

| Where | How |
| ----- | --- |
| The board | Hold **B** for five seconds |
| This page | Network tab, **Erase everything and start again** |
| The console | `factory-reset confirm` |

It is the way back when the page cannot be reached at all: a board whose saved
network no longer exists, or one whose web interface was turned off on a
network that has since gone. It does not touch the firmware, only what the
board remembers.

## 7. Diagnostics

Everything the board knows about itself. Worth reading when something sounds
wrong.

| Row | What to look for |
| --- | --- |
| Stream buffer | Should hover, not sit empty or pinned full |
| HTTP status | 200 when playing |
| Reconnects | Climbing means an unreliable station |
| Last error | The reason the stream last stopped |
| Decoded frames | Should climb steadily, roughly 40 per second |
| Decode errors | A few at the start are normal. Climbing is not |
| Stream format | Sample rate, channels and bitrate the station is sending |
| Resampler trim | Parts per million of correction. Near 5000 means the source rate is far from what the chain expects |
| AGC gain | What the loudness AGC is adding or removing right now, in dB |
| Modulator FIFO | Should sit near half full |
| Modulator underruns | Should stop climbing once a station is playing |
| Free heap | Falling steadily over hours would suggest a leak |
| Uptime | Resets to zero if the board restarted without you asking |

The most useful pair is **decoded frames** and **modulator underruns**. Frames
climbing with underruns static means the whole chain is healthy.

## 8. Tuning a receiver

Set the receiver to the carrier frequency shown in the header. With the
default 200 kHz you need a longwave radio: most portable radios sold outside
Europe are medium-wave and FM only, and will not reach it.

Hold the receiver near the loop. Signal falls off very quickly with distance,
which is the point.

If you hear the station on the receiver but the sound is distorted, try
lowering the modulation depth, then the programme gain.

If you hear nothing, check the header says `ON AIR`, check Now playing shows a
station and the modulation meter is moving, then check your output network.

## 9. The serial console

Connect the native USB port and open a terminal at 115200 baud. Press Enter
for the `amtx>` prompt. It works whether or not Wi-Fi is up, which is the
point of it: the web page is unreachable exactly when the network is the thing
that is broken.

| Command | What it does |
| --- | --- |
| `help` | Lists the commands |
| `status` | One line of state, meant to be read by a script. Shared fields first, then `carrier0`, `hz0`, `playing0` and so on per transmitter, then `host` and `web` |
| `state` | Everything the page shows, as one line of JSON |
| `play a 0` | Play station 0 on transmitter A. `play b http://...` plays a URL on B |
| `stop a` | Stop transmitter A's stream |
| `station list` | The stations, numbered from 0 |
| `station add "Name" http://...` | Add one. Quote a name with spaces |
| `station delete 3`, `station move 3 0` | Delete, reorder |
| `station default a 0` | Station 0 plays on A at power-on. `none` clears it |
| `station trim 2 120` | Station 2 plays 20% louder |
| `rf a` | Transmitter A's settings |
| `rf a hz 198000 depth 60` | Change any of `on hz depth lpf gain level agc agct fade faderate fadedepth` |
| `tone a on 1000`, `tone a off` | Test tone |
| `discover tag jazz` | Search the directory by `name`, `tag` or `country` |
| `discover play a 2`, `discover save 2` | Play or save result 2 |
| `hostname`, `hostname kitchen` | Show or set the hostname |
| `web`, `web off`, `web on` | Show, stop or start the web interface. Saved |
| `factory-reset` | Explains what would be lost and does nothing |
| `factory-reset confirm` | Erases everything saved and restarts |
| `wifi scan` | What the radio can see |
| `wifi join <ssid> <pass>` | Join now, and save it if it works |
| `wifi save <ssid> <pass>` | Save without joining |
| `wifi list` | Saved networks |
| `wifi forget` | Delete all saved networks |
| `log off` | Stop the log scrolling past |
| `log on` | Start it again |
| `reboot` | Restart |

`wifi join` tries for up to 15 seconds. It retries by itself when the router
misses a frame or a scan misses the network. When it gives up, it says why:

| Message | Usually means |
| --- | --- |
| `reason 201, no network with that name` | A typo. Names are case-sensitive; copy it from `wifi scan` |
| `reason 15` or `204`, `wrong password` | The password, or its case |
| `reason 2, router did not answer authentication` | The router ignores the board. Check for a MAC filter on the router; the board's MAC is in the boot log |
| `reason 210` or `211, network security not supported` | The router is WPA3-only. Allow WPA2 as well |

Every command except `status`, `log` and `reboot` finishes with a line
starting `ok` or `error:`, which says whether it worked. `tools/amtx-programmer/` drives the
board through them with buttons and dialogs.

`log off` is there so the console can be driven by a script. With the log
quiet, `status` returns a single parseable line and nothing else. Logging
comes back on at every boot, because a silent board looks like a dead one.

The baud rate does not really matter. The console is a USB device rather than
a real serial port, so the setting is negotiated away.

## 10. Before you transmit

This is a transmitter, and two facts about it are not negotiable.

**Fit an output low-pass network to each pin.** Without it, a square-wave
carrier radiates harmonics across the whole medium-wave band and interferes
with every station a domestic radio can tune. Design 03 §4 has a network that
works. With two transmitters you need two of them: coupling both pins into one
network lets the carriers intermodulate, and the products land where neither
carrier is.

**Keep the field inside the room.** The default 200 kHz sits in the longwave
broadcast band, 2 kHz from BBC Radio 4 on 198 kHz. Use an inductive loop
beside the receiver, not an antenna. Deliberate radiation there is licensed in
the UK and in most other places, and this project holds no licence. What you
radiate, and the rules where you live, are yours to check.

Nothing in this project has been measured off-air. The audio chain is tested
and the firmware runs, but what the pin actually radiates has never been
observed on a receiver or an analyser.

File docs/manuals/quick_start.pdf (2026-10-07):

# Quick Start

From a downloaded release to a transmitter playing internet radio, with no compiler and no ESP-IDF. About twenty minutes, most of it waiting for downloads.

This is the short path. It flashes a firmware binary that is already built. If you want to change the firmware and build it yourself, read the Installation Manual instead. To make the case and wind the antennas, read the Build Manual.

## Contents

1. What you need
2. Get the release
3. Install Python
4. Plug the board in
5. Flash it
6. Talk to the board
7. Put it on your Wi-Fi
8. Hear something
9. Before you leave it running
10. When it goes wrong

## 1. What you need

Item | Notes
An ESP32-S3 board | 8 MB flash. A bare "mini" dev board is fine. No display, no audio hardware, no buttons needed
A USB cable | Data, not charge-only. A charge-only cable looks like a dead board
A Wi-Fi network | 2.4 GHz. The board has no 5 GHz radio
An AM receiver | Longwave capable, if you keep the default 200 kHz and 250 kHz carriers
A PC | Windows, macOS or Linux

You do not need the 3D-printed case, the loop antennas or any soldering to get to the end of this guide. The board will transmit a few centimetres on its own, which is enough to prove it works with a receiver sitting next to it.

One thing to get right before anything else

Your board probably has two USB sockets. One is a USB-to-serial bridge (CH343, CP210x or similar). The other is the ESP32-S3's own USB peripheral.

Use the native USB port. The firmware puts its console there. On the bridge you will see the ROM bootloader banner and nothing else, and you will conclude the board is broken when it is not.

On Windows the native port appears in Device Manager as USB JTAG/serial debug unit , with a USB Serial Device COM number. On Linux it is usually /dev/ttyACM0 , on macOS /dev/cu.usbmodem* .

If the board has only one socket, that is the native one.

## 2. Get the release

Go to the latest release (https://github.com/GarethDaviesLondon/esp32-am-transmitter/releases/latest) and download the source code zip, not just the loose .bin files. The zip carries the flashing tool as well as the firmware, and you want both.

Unzip it anywhere. You will end up with a directory holding, among other things:

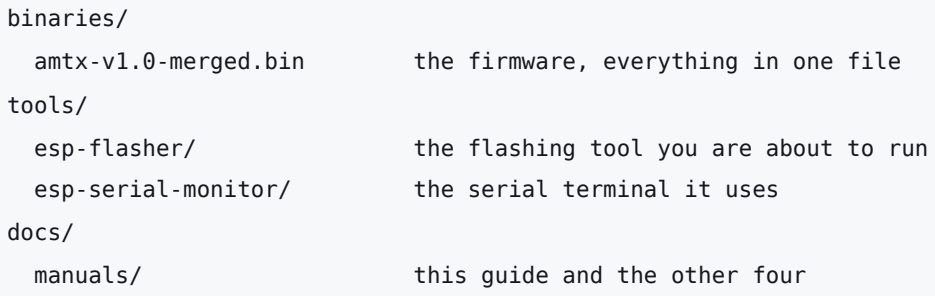
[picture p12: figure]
binaries/; tools/; esp-serial-monitor/; the serial terminal it uses; docs/; manuals/; this guide and the other four

amtx-v1.0-merged.bin | the firmware, everything in one file
esp-flasher/ | the flashing tool you are about to run

The version number in the .bin filename will match the release you downloaded, so amtx-v1.0-merged.bin may read v1.1 or later. Use whatever is actually there.

## 3. Install Python

The flashing tool is a Python program. It needs Python 3.10 or newer.

Windows: install from python.org. (https://www.python.org/downloads/) On the first screen of the installer, tick Add python.exe to PATH. This is the step everybody misses, and without it the commands below report python: command not found .
macOS: brew install python , or the python.org installer.
Linux: Python 3 is already there. You also need Tk, which is packaged separately: sudo apt install python3-tk on Debian or Ubuntu. Without it the tool stops with ModuleNotFoundError: No module named 'tkinter' .

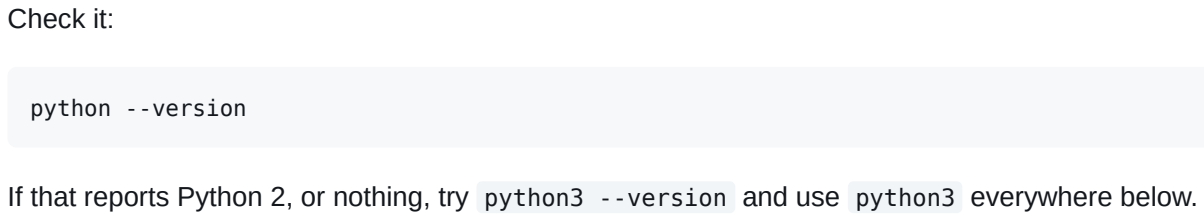
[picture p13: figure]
Check it:; python --version

If that reports Python 2, or nothing, try python3 --version and use python3 everywhere below.

Now install the two packages the tool needs. From the directory you unzipped:

That is pyserial , which finds the board, and esptool , which writes the flash. Nothing else.

## 4. Plug the board in

Connect the board's native USB port to the PC.

A brand-new board will look broken. A blank ESP32-S3 has nothing to boot, so the ROM gives up and the watchdog resets it, about every 2.6 seconds. On native USB that means the board appears on the bus, vanishes, and appears again, over and over. Windows may chime repeatedly. This is correct behaviour for an empty board and the flasher is built to cope with it.

## 5. Flash it

Change into the flasher's directory and run it:

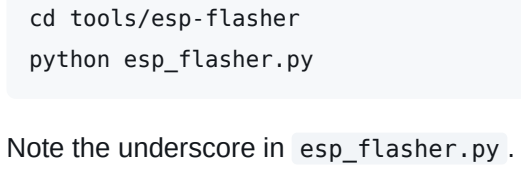
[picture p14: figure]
cd tools/esp-flasher; python esp_flasher.py; Note the underscore in esp_flasher.py .

A window opens with three sections: Board, Firmware, Flash.

1. Board. Your board is in the list. A new one is labelled something like boot-looping (resets every 2.6s) , which is the tool telling you it has noticed the loop in §4. Select it and press Probe board.

The probe only reads. It reports the chip, the flash size, the MAC address, and what is currently in each region. A blank board reports Bootloader: blank and is left in download mode, where it stops looping and sits still on the bus.

2. Firmware. The tool preselects the newest build*/ directory it can find. A release download has no build/ directory, so there will be nothing selected or the wrong thing selected. Press .bin file... and choose binaries/amtx-v1.0-merged.bin from the unzipped release.

The tool recognises a merged image and places it at offset 0x0 by itself. You do not need to touch the offset box.

3. Flash. Leave Auto ticked and press Flash. A confirmation lists exactly what it is about to write and why. Accept it.

Writing takes a few seconds. Leave Erase whole flash first unticked: on a new board there is nothing to erase, and on a used board it also wipes saved Wi-Fi networks and settings.

When the board comes back on the bus, a Monitor tab opens on it by itself.

If you would rather not use the tool

The flasher is the friendlier route, but the plain esptool command does the same job in one line, and it is the route that has had the most use on real hardware:

python -m esptool --chip esp32s3 -p COM5 write_flash 0x0 binaries/amtx-v1.0-merged.bin

Replace COM5 with your port. On Linux that is /dev/ttyACM0 , on macOS /dev/cu.usbmodem* .

## 6. Talk to the board

The Monitor tab has two panes. Boot output and log messages scroll in the [SYS] pane on top. The console is the terminal pane below.

Click the lower pane before you type. Keystrokes go to whichever pane has focus, and typing into the log pane does nothing at all, which is a dispiriting way to start.

You should see the board boot, join nothing yet, and settle. Press Enter and you get the prompt:

amtx>

Log messages keep scrolling past while you type, which makes the console hard to read. Turn them off:

amtx> log off

Now check the firmware is really running and talking to you:

That lists every command the board understands, in alphabetical order. You should see play , station , rf , tone , discover , wifi , hostname , web , status , state , log , factory-reset

and reboot .

If help lists those commands, the firmware is on the board and working. That is the milestone. Everything from here is configuration.

One more worth trying, because it prints the whole state of the board on one line:

amtx> status

## 7. Put it on your Wi-Fi

The board has no network yet. There are two ways to give it one. They reach the same result and save to the same place, so use whichever suits you.

Option A: the setup page, from a phone

Best if you are away from the PC, or setting up a board that is already in its case.

With no saved network, the board raises its own open Wi-Fi access point called AMTX-Setup .

1. On a phone or laptop, join AMTX-Setup . It has no password.
2. The setup page opens by itself, as a captive portal. If it does not, open a browser and go to http://192.168.4.1 .
3. Press Scan, pick your network, type its password, and save.
4. The board reboots and joins.

Once it has joined, the access point goes away and the board is at http://amtx.local , or at the address shown on the page's Network tab. That page is the full interface: stations, both transmitters, RF settings, diagnostics.

Option B: the console, from the PC

Best if you are already sitting at the Monitor tab, which you are.

See what is in range:

amtx> wifi scan

You get a numbered list with signal strengths:

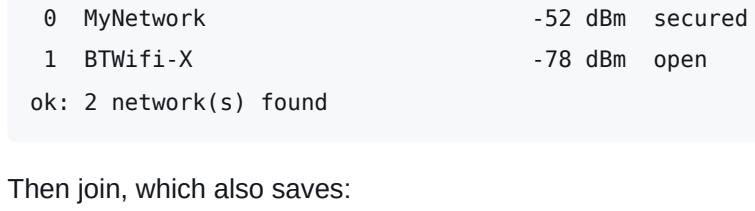
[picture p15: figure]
0 MyNetwork; -52 dBm secured; 1 BTWifi-X; -78 dBm open; ok: 2 network(s) found; Then join, which also saves:

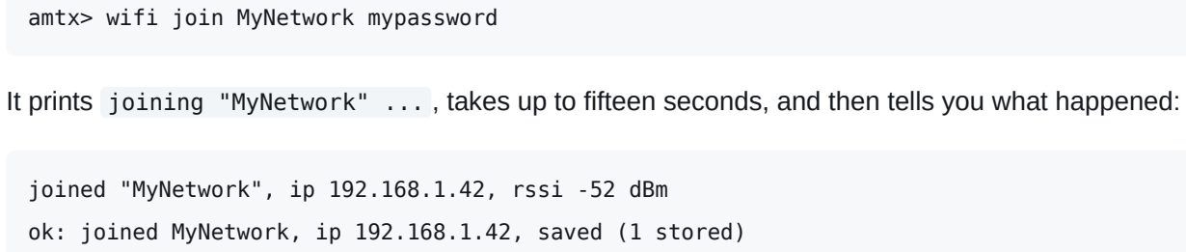
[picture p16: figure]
amtx> wifi join MyNetwork mypassword

It prints joining "MyNetwork" ... , takes up to fifteen seconds, and then tells you what happened:

joined "MyNetwork", ip 192.168.1.42, rssi -52 dBm
ok: joined MyNetwork, ip 192.168.1.42, saved (1 stored)

Put double quotes round anything containing a space:

amtx> wifi join "My Home Network" "pass phrase with spaces"

Useful companions:

Command | Does
wifi status | Where it is now, and its address
wifi list | The networks it has saved
wifi save <ssid> [pass] | Save for next boot without joining now
wifi forget | Delete every saved network

A joined board prints its address. Open http://amtx.local in a browser and you have the web interface, the same as Option A.

## 8. Hear something

A factory-fresh board comes up with two stations already in its list, one on each transmitter:

Transmitter | Default station | Default carrier
A | Radio Swiss Jazz | 200 kHz
B | BBC World Service | 250 kHz

So once it is on your network it should already be transmitting. Check with:

amtx> status

Now tune a receiver. Put it next to the board, switch it to longwave, and tune slowly around 200 kHz. Without an antenna the range is a few centimetres, so the receiver needs to be touching or nearly touching the board.

If you are hunting for the carrier and want something unmistakable, a steady tone is far easier to find than music:

amtx> tone a on 1000

That replaces the programme on transmitter A with a 1 kHz tone. Find it on the dial, then put the music back:

amtx> tone a off

Heard it? That is the whole chain working: Wi-Fi, the stream, the decoder, the modulator and the carrier.

For everything you can do from here, read the User Manual.

## 9. Before you leave it running

Two things to understand, and they are not formalities.

It transmits in a licensed broadcast band. Longwave runs from 148.5 kHz to 283.5 kHz. The default 200 kHz carrier sits inside it, a couple of kilohertz from BBC Radio 4's allocation on 198 kHz. Deliberate radiation there needs a licence in the UK and in most other places, and this project has none. Keep the field inside the room: no outdoor wire, nothing connected to mains wiring, nothing resembling a real antenna. What you radiate, and the rules where you live, are yours to check.

There is no output filter in a bare-board build. The carriers are square waves, and a square wave at 200 kHz radiates odd harmonics at 600 kHz, 1.0 MHz and upward, across the whole medium-wave band. For a few minutes on a bench with a receiver beside it, that is tolerable. For anything left running, fit the series resistor and low-pass network for each carrier pin, as the Build Manual describes. Each carrier needs its own filter: one filter shared between both lets them intermodulate.

## 10. When it goes wrong

What you see | What it is
python: command not found on Windows | Python was installed without Add python.exe to PATH. Re-run the installer and tick it
No module named 'tkinter' | Linux, missing Tk. sudo apt install python3-tk
No board in the list | Charge-only cable, or the wrong USB socket. See §1
Only the ROM banner, no amtx> prompt | You are on the USB-to-serial bridge, not the native port. See §1
Board appears and vanishes repeatedly | Normal for a blank board. Flash it. See §4
Could not open COM5, the port is busy | Something else holds the port. Close other terminals. A terminal whose window you closed can leave its process running
Nothing selected in the Firmware section | Expected on a release download: there is no build/ directory. Press .bin file.... See §5
The flasher cannot catch the board | Put it in download mode by hand: hold BOOT, press and release RESET, release BOOT, then probe again
unrecognised command from a command in §6 | The firmware on the board is older than this guide. Flash the release binary
Typing does nothing in the Monitor tab | Click the lower pane first. See §6
Joined Wi-Fi but amtx.local will not open | Use the IP address from wifi status . Some networks and some Windows setups do not resolve .local names
No audio, carrier present | The station URL may be dead. Try station list , then play a <index> with another, or discover name jazz to find one

Starting over

To wipe everything saved, including Wi-Fi networks and station changes, and return the board to how it arrived:

amtx> factory-reset confirm

## Where to go next

Manual | For
User Manual | Driving it: the page, the stations, both transmitters, tuning a receiver
Build Manual | Making the real thing: printing the case, winding the antennas, wiring, the output filters
Installation Manual | Building the firmware from source, with ESP-IDF
Technical Manual | How the firmware works inside, for changing it

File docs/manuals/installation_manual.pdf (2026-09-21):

# Installation Manual

How to get from a bare ESP32-S3 and a clean machine to a transmitter playing internet radio. Follow it in order. Each step ends with something you can check.

For day-to-day use once it runs, see the User Manual. For how it works inside, see the Technical Manual.

## Contents

1. What you need
2. The output network, which is not optional
3. Installing the toolchain
4. Building
5. Flashing
6. First boot and joining a network
7. Checking it works
8. When it goes wrong

## 1. What you need

Hardware

Item | Notes
ESP32-S3 board | 8 MB flash. Verified on an ESP32-S3R8, chip revision v0.2, with 8 MB embedded PSRAM
USB cable | Data, not charge-only
Passives for two output networks | One per carrier. See Â§2 and Design 03 Â§4
An AM receiver | Longwave capable if you keep the default 200 kHz carrier

The board needs no audio hardware, no display and no buttons. Everything is
driven from a web page it serves itself.

Your board may expose two USB ports. One is a USB-to-serial bridge (CH343, CP210x or similar). The other is the ESP32-S3's own USB peripheral. Use the native USB port. The firmware routes its console there
( CONFIG_ESP_CONSOLE_USB_SERIAL_JTAG ), so the bridge shows you the ROM
bootloader banner and nothing else. On Windows the native port appears in

Device Manager as USB JTAG/serial debug unit with a USB Serial Device
COM number.

Host machine

You need Git, Python 3 and about 4 GB of disk. The ESP-IDF installer fetches its own compilers, so you do not need a toolchain first.

Windows users: keep the paths short. C:\esp works. A deep path under a user profile can push the build past the Windows path length limit in ways that report themselves as unrelated compiler errors.

## 2. The output network, which is not optional

Two things stand between this project and a nuisance.

Fit a low-pass network to each carrier pin. The carriers are square waves.
A square wave at 200 kHz radiates odd harmonics at 600 kHz, 1.0 MHz, 1.4 MHz and upward, at a third, a fifth and a seventh of the fundamental. Those land across the whole medium-wave broadcast band. A bare wire on GPIO 4 splatters over every station a domestic radio can tune. Design 03 Â§4 gives a network that works. This is recorded as KI-02 .

The firmware runs two transmitters, on GPIO 4 and GPIO 5 by default. Each needs its own network. Coupling both into one lets them intermodulate, and 200 kHz has its third harmonic at 600 kHz, close enough to a second carrier in the 250 to 300 kHz range that the filtering has to keep them apart rather than merely tidy each one up. That is KI-08 .

Keep the field in the room. 200 kHz sits inside the longwave broadcast
band, 2 kHz from BBC Radio 4 on 198 kHz. Use an inductive loop under or beside the receiver, not an antenna. Deliberate radiation in that band is licensed in
the UK and in most other places, and this project holds no licence. What you actually radiate, and the rules where you live, are yours to check. This is
recorded as KI-04 .

Neither point is a formality. Build the network before you connect anything to the pin.

What the built unit actually has

AM transmitter: what is wired to what

Two independent transmitters, one loop each. They share the board's ground and nothing else.

Waveshare
ESP32-S3-Zero

ESP32-S3

USB-C 5 V in

IO 4

IO 5

GND

TRANSMITTER A · carrier 200 kHz by default

220 Ω

Loop A · 5 turns
0.3 mm enamelled copper on the lid's pillars, about 56 × 27 mm

TRANSMITTER B · carrier 250 kHz by default

220 Ω

Loop B · 5 turns
the second winding, on the same four pillars

board ground: the only connection between the two

No output filter is fitted: a square wave at 200 kHz radiates odd harmonics across medium wave. Read KI-02 and design 03 §4 first.

One transmitter per pin: GPIO through a 220 ohm series resistor, into a
five-turn loop, back to the board's ground. No filter, which is the
shortcut described in Design 03 Â§4a and Â§4b and not a recommendation. It works at this drive with the receiver in the same room, and nobody has put a
spectrum analyser on it. If you build one with more drive, a longer antenna or
a smaller resistor, fit the network in Design 03 Â§4.


The lid carries both windings and both resistors, and the base carries the
board. The enclosure is designs/2026-09-tx-case/ .

## 3. Installing the toolchain

The project is pinned to ESP-IDF v5.3.2. Other v5.x releases will probably work and have not been tried.

Clone the SDK. A shallow clone is enough and saves a long wait:

git clone --depth 1 --recursive --shallow-submodules \

Install the tools for this chip:

# Windows PowerShell

$env:IDF_PATH = 'C:\esp\esp-idf' $env:IDF_TOOLS_PATH = 'C:\esp\tools' C:\esp\esp-idf\install.ps1 esp32s3

# macOS and Linux

export IDF_PATH=~/esp/esp-idf
cd $IDF_PATH && ./install.sh esp32s3

This downloads roughly 2 GB and takes 15 to 30 minutes. It fetches the Xtensa and RISC-V compilers, CMake, Ninja, OpenOCD, and builds a Python environment.

Check: open a new shell, activate the environment, and ask for a version.

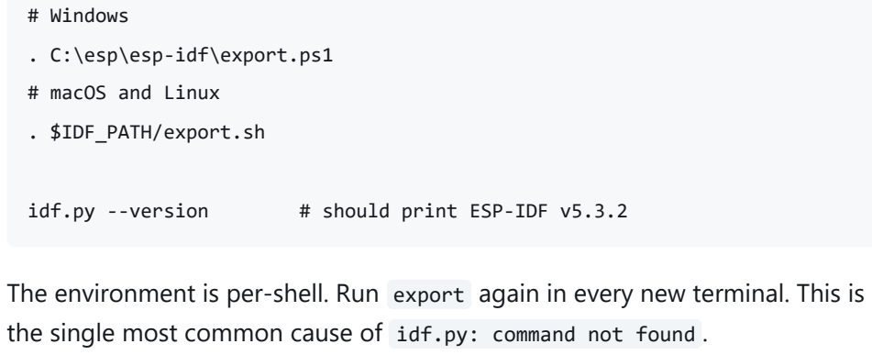
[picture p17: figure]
# Windows; . C:\esp\esp-idf\export.ps1; # macOS and Linux; . $IDF_PATH/export.sh; idf.py --version; # should print ESP-IDF v5.3.2

The environment is per-shell. Run export again in every new terminal. This is the single most common cause of idf.py: command not found .

## 4. Building

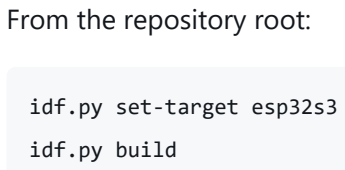
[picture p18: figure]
From the repository root:; idf.py set-target esp32s3; idf.py build

The first build resolves two managed components from the Espressif registry,
chmorgan/esp-libhelix-mp3 and espressif/mdns , then compiles about a
thousand files. Allow several minutes. Later builds take seconds.

Check: the build ends with a size line and no warnings.

amtx.bin binary size 0x11c0b0 bytes. Smallest app partition is 0x300000 bytes.

You do not need idf.py menuconfig . Everything it sets has a working default, and Wi-Fi is configured from the board itself. Use it only to change the RF pin, the audio low-pass, or the two stations a fresh board starts on (Radio Swiss Jazz on A, BBC World Service on B). Anything you enter there
lands in sdkconfig , which is deliberately not tracked by Git because it can hold a Wi-Fi password.

Host-side tests, no hardware needed

The audio maths builds and runs on your machine:

make -C test/host test

Twenty-seven checks covering the filters, the resampler, the limiter and the arcsine duty table. They should all pass. On Windows with MinGW, use
mingw32-make CC=gcc .

## 5. Flashing

Find the port. On Windows it is the USB Serial Device COM number that appears when you connect the native USB port. On Linux it is usually /dev/ttyACM0 , on
macOS /dev/cu.usbmodem* .

idf.py -p COM18 flash

Each of the three images ends with Hash of data verified .

Or use the flasher. python tools/esp-flasher/esp_flasher.py finds the
board, reads what is on it, writes the bootloader, partition table and app from build/ (or only the app, when the rest already matches), and opens a serial monitor on the board afterwards. It needs no ESP-IDF shell, only
pip install -r tools/esp-flasher/requirements.txt . See its README.md .

A new board that keeps disappearing. A blank ESP32-S3 resets every couple of seconds and drops off USB each time ( LL-06 ). The flasher catches it anyway. With idf.py , hold BOOT, press and release RESET, release BOOT, then flash: the board stays put in download mode.

If the port is busy: close anything else holding it. A serial terminal
keeps the port open, and Windows will not share it. The error is
Could not open COM18, the port is busy or doesn't exist . Note that a terminal
whose window you closed can leave its process running and still holding the port.

## 6. First boot and joining a network

With no saved network, the board raises its own open access point.

1. Look for a Wi-Fi network called AMTX-Setup and join it. It takes about 30 seconds to appear after a reset.
2. A setup page should open by itself. If it does not, browse to
http://192.168.4.1 .
3. Open the Network tab and press Scan for networks.
4. Pick your network from the list. Using the list rather than typing the name matters: the scan only returns 2.4 GHz networks, and the ESP32-S3 has no 5 GHz radio, so a hand-typed 5 GHz name will never join.
5. Type the password. Press the eye button beside the field to check it before you commit.
6. Press Save and join.

A dialog tells you the board is restarting to join. The setup portal will
disconnect at this point, and that is the success path, not a failure: the
access point has to come down before the board can join your network.

Or do it over the USB cable instead. python tools/amtx-programmer/amtx_programmer.py finds the
board, opens its console
and gives you the same settings as buttons and dialogs: networks, stations,
both transmitters, the hostname and the web interface. It is the only route in
once the web interface has been turned off, and it needs no phone.

Reconnect your phone or laptop to your own network and open http://amtx.local . If another transmitter on the network already answers to that name, set this
one's hostname on the Network tab, or with hostname <name> on the serial console, and use http://<name>.local from then on.

If the password was wrong, the board gives up after about 15 seconds per saved network and brings AMTX-Setup back, so you can rejoin and try again.

If mDNS does not work

Some networks and some operating systems do not resolve .local names. Find
the address instead. Connect the native USB port, open a serial terminal at
115200 baud, and wait up to 30 seconds:

I (30300) wifi: wifi up: connected to "YourNetwork", ip 192.168.0.123, rssi -57 dBm, drops 0

That heartbeat prints every 30 seconds whether or not anything has changed, so
silence means nothing is running rather than nothing has changed.

You can also ask the board directly. Press Enter in the terminal to get the amtx> prompt and type status .

## 7. Checking it works

Work down this list. Each line is something you can see.

Check | What you should see
It boots | webui: web interface up on port 80
It joined | wifi up: connected to "...", ip ... every 30 s
The web UI answers | http://amtx.local loads the page
The carrier runs | Header reads ON AIR 200.0 kHz 70%
A stream plays | Now playing shows a station and playing
Audio decodes | Diagnostics shows decoded frames climbing, roughly 40 per second
The modulator is fed | Modulator FIFO near half full, underruns not climbing
A radio hears it | Tune the receiver to the carrier frequency

The last line is the only one this project has never checked. Nothing here has been measured off-air: no receiver, no spectrum analyser, no field-strength reading. The signal chain is verified up to the duty register and no further.

If it is set up wrong and you cannot reach it

Hold the board's BOOT button (marked B) for five seconds while it is running. It forgets every station, every saved network, both transmitters' settings, its hostname and whether the web interface runs, then restarts and raises AMTX-Setup again. The firmware stays; this only clears what the board remembers. User Manual Â§6 has the detail.

That is the answer to the two states nothing else recovers: a board whose only saved network no longer exists, and a board whose web interface was turned off on a network you can no longer join.

## 8. When it goes wrong

idf.py not found. The environment is per-shell. Run the export script again.

Build fails on a missing component. The first build needs to reach components.espressif.com . Behind a restrictive proxy it cannot, and the error does not say so. LL-03 records the workaround.

Nothing on the serial port but a ROM banner. You are on the USB-to-serial bridge, not the native USB port. Move the cable.

The port is busy. Something else has it open. See Â§5.

The port keeps appearing and vanishing. The flash is blank or corrupt and the chip is boot-looping. Flash it; see Â§5 and LL-06 .

The setup portal will not take a password. Firmware before the KI-07 fix reset itself on every settings write, so no credential could ever be saved. Check you are running a current build. The symptom is a board that joins your network correctly and then reappears on AMTX-Setup after a reboot with nothing saved.

A station will not play. Check Diagnostics for the HTTP status. 302 on a current build means the redirect chain ran past its limit. Anything that is not MP3 will connect and then produce silence, because libhelix is the only decoder compiled in.

Your browser keeps probing. While you sit on AMTX-Setup , phones and browsers poll for a captive portal every few seconds. That is normal and stops once the board has real internet.

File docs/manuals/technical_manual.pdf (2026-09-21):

# Technical Manual

How the firmware works, for someone about to change it. The design documents in docs/design/ carry the reasoning behind each decision; this manual is the working reference that sits above them.

For building and flashing, see the Installation Manual. For operating it, see
the User Manual.

## Contents

1. The signal chain
2. Why duty-cycle AM needs an arcsine table
3. Tasks, cores and the real-time contract
4. Module map
5. Storage
6. HTTP API
7. Serial console
8. Memory
9. Traps that have already been paid for
10. Limits and what would lift them

## 1. The signal chain

There are two of these, indexed 0 and 1, and they are independent transmitters. Each has its own station, carrier frequency, modulation depth, audio low-pass, gain, output pin and power-on default. They share one Wi-Fi connection, one station list, one modulation timer and the 80 MHz LEDC clock.

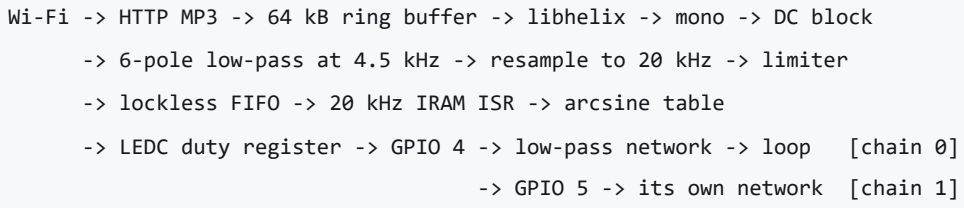
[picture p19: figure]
-> GPIO 5 -> its own network [chain 1]

Wi-Fi -> HTTP MP3 -> 64 kB ring buffer -> libhelix -> mono -> DC block
-> 6-pole low-pass at 4.5 kHz -> resample to 20 kHz -> limiter
-> lockless FIFO -> 20 kHz IRAM ISR -> arcsine table
-> LEDC duty register -> GPIO 4 -> low-pass network -> loop [chain 0]

The ring buffers live in PSRAM; everything the ISR touches stays in internal DRAM. Each chain runs its own resampler trim loop, because two stations drift against this board's crystal independently.

Each stage exists for a reason.

Ring buffer. 64 kB of raw MP3, about four seconds at 128 kbit/s. Absorbs network jitter so the decoder never starves on a slow TCP window.

Mono downmix. The carrier has one envelope. Two channels are averaged with headroom so full-scale correlated material cannot wrap.

DC block. A one-pole high-pass at 25 Hz. MP3 decoders emit a DC offset on some material, and DC here shifts the carrier bias rather than being inaudible.

Low-pass. Three cascaded biquads, a 6th-order Butterworth at 4.5 kHz. It
is 41 dB down at 10 kHz where a 2nd-order design manages 14 dB. This is what keeps the transmission inside a 9 kHz channel.

Resampler. Linear interpolation from the stream rate to 20 kHz. It also
nudges its own step to hold the sample FIFO near half full, absorbing the drift between the station's clock and this board's crystal. Without that the FIFO walks to one end and clicks every few minutes. The correction is bounded at 5000 ppm, far more than two crystals can differ and small enough to be inaudible.

AGC. Between the fixed gain and the limiter. Tracks programme RMS and drives gain towards a target, because stations differ by more than 10 dB in average level and a peak limiter cannot close that gap: it only pushes peaks down. Asymmetric slew, 200 ms down and 3 s up, bounded -6/+18 dB, gated at -50 dBFS so speech pauses do not lift the noise floor. See EH-11 .

Limiter. 1 ms attack, 250 ms release, ceiling at 0.95 of full scale. Last
in the chain, as the safety net: the AGC targets an average, and peaks are not its job.

FIFO. 2048 samples, 102 ms at 20 kHz. Single producer, single consumer, lockless. The decode task writes the head, the ISR writes the tail, and neither touches the other's index. This is why the decode task and the ISR must share a core.

## 2. Why duty-cycle AM needs an arcsine table

This is the part of the design worth understanding before changing anything.

The amplitude a square wave radiates at its own frequency goes as sin(pi*D) , where D is the duty cycle. That function peaks at 50% duty, so its slope
there is zero. Modulating duty about 50%, which is the obvious reading of the brief, produces almost no amplitude modulation. Swinging from 25% to 75% moves the radiated amplitude from 0.707 to 0.707.

So the firmware puts the modulation peak at 50% duty, sits the unmodulated carrier at 1/(1+m) of it, and inverts the sine into a 512-entry table built
once at configuration time:

D = asin(a) / pi

The interrupt is then a lookup, an add, a clamp and a register write. The envelope comes out linear in the sample.

For the default depth of 0.70 the quiescent duty is asin(1/1.70)/pi = 0.2002 , which lands on 51 of 256 register steps. Seeing quiescent duty 51/256 in the boot log is confirmation the table built correctly.

This is KI-01 and LL-02 . The host test suite asserts it, including a check
that the brief's original 50%-centred scheme really is flat.

Noise shaping

At 200 kHz on the 80 MHz LEDC clock there are 400 clocks per period, so the duty register has 8 usable bits. Around the bias point that leaves roughly 6.5 bits of amplitude resolution. First-order error feedback on the duty quantiser carries the rounding error into the next tick, which pushes most of that noise above the 4.5 kHz audio band. Two adds in the ISR. Set RF_NOISE_SHAPING to 0 to compare on a scope.

None of this has been measured on hardware.

## 3. Tasks, cores and the real-time contract

Task | Core | Priority | Stack | Count
Modulation ISR | 1 | interrupt | n/a | 1, serving every chain
Decode | 1 | 10 | 12288 | one per chain
Stream | 0 | 5 | 8192 | one per chain
Wi-Fi, lwIP, httpd | 0 | IDF defaults | IDF defaults | 1
Console REPL | 0 | IDF default | 4096 | 1

Measured with two chains playing different stations on an ESP32-S3R8, the module with 8 MB octal PSRAM: each decoder sustains 42.1 frames/s, which is the correct rate for 48 kHz MP3, with modulator underruns static and both FIFOs near full. Core 1 carries two decoders and the 20 kHz ISR without strain.

A quad-PSRAM module does it too. Measured on a Waveshare ESP32-S3-Zero (2 MB quad PSRAM) on 2026-09-18: two 48 kHz 128 kbit/s streams at once, 41.8 and 41.8 frames/s, zero underruns, on both the pre-refactor build and the refactored one. The same board had been seen running 21% slow on both chains shortly after a flash, which is KI-14 : unexplained, not reproducible since,
and left open rather than explained away.

The ISR's own cost has never been measured directly, and WI-1 's decode-cost measurement is still outstanding. Know which module you have before trusting either set of numbers.

The split is not arbitrary. Core 0 carries everything that can block on the network. Core 1 carries the audio path and nothing else, so no decode ever waits on a socket.

Three rules hold the real-time behaviour together.

The modulation ISR must not touch flash. It is IRAM_ATTR , its tables are
DRAM_ATTR , and sdkconfig.defaults sets CONFIG_GPTIMER_ISR_IRAM_SAFE , CONFIG_GPTIMER_CTRL_FUNC_IN_IRAM and CONFIG_GPTIMER_ISR_HANDLER_IN_IRAM .
Without those the ISR lives in flash and the first cache miss during an SPI flash operation takes the carrier with it.

The ISR must be registered from core 1. A gptimer ISR is allocated on the core that registers it, so app_init() runs from a task pinned to
TASK_CORE_AUDIO , not from app_main() . See main.c . Every decode task is
pinned there too, for the same FIFO reason.

Stop the ISR across a flash write. Being IRAM-safe is necessary but not sufficient. Taking a 20 kHz interrupt continuously through a cache-disabled window starves the interrupt watchdog and the board resets before the write
lands. carrier_suspend() and carrier_resume() bracket every nvs_commit() .
This is KI-07 and Â§9 covers what it cost to find.

## 4. Module map

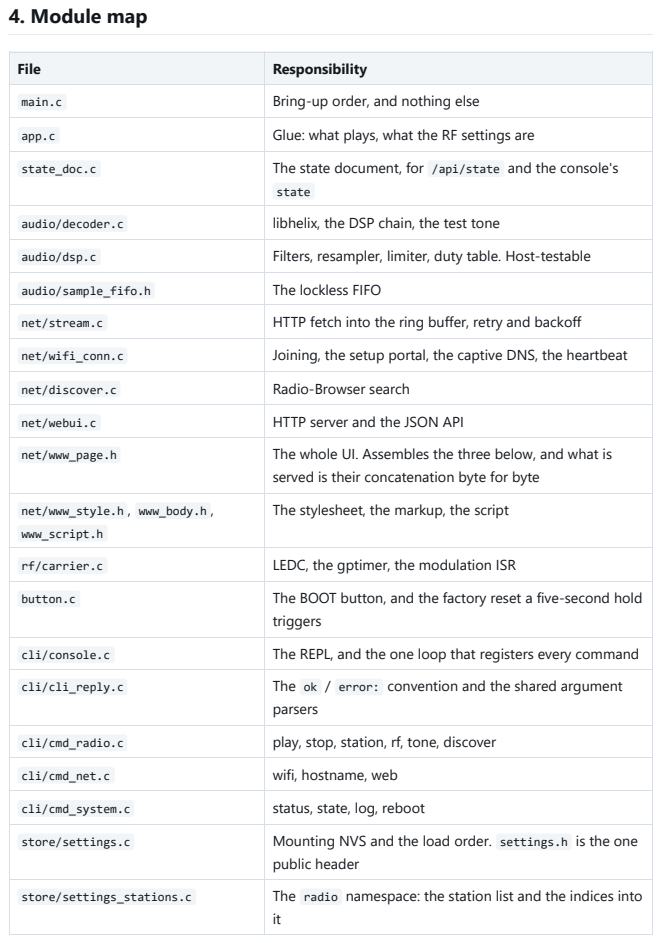
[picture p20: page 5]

File | Responsibility
main.c | Bring-up order, and nothing else
app.c | Glue: what plays, what the RF settings are
state_doc.c | The state document, for /api/state and the console's state

audio/decoder.c | libhelix, the DSP chain, the test tone
audio/dsp.c | Filters, resampler, limiter, duty table. Host-testable

audio/sample_fifo.h | The lockless FIFO
net/stream.c | HTTP fetch into the ring buffer, retry and backoff
net/wifi_conn.c | Joining, the setup portal, the captive DNS, the heartbeat
net/discover.c | Radio-Browser search
net/webui.c | HTTP server and the JSON API
net/www_page.h | The whole UI. Assembles the three below, and what is served is their concatenation byte for byte

net/www_style.h , www_body.h , www_script.h | The stylesheet, the markup, the script

rf/carrier.c | LEDC, the gptimer, the modulation ISR
button.c | The BOOT button, and the factory reset a five-second hold triggers

cli/console.c | The REPL, and the one loop that registers every command
cli/cli_reply.c | The ok / error: convention and the shared argument parsers

cli/cmd_radio.c | play, stop, station, rf, tone, discover
cli/cmd_net.c | wifi, hostname, web
cli/cmd_system.c | status, state, log, reboot
store/settings.c | Mounting NVS and the load order. settings.h is the one public header

store/settings_stations.c | The radio namespace: the station list and the indices into it

File | Responsibility
store/settings_wifi.c | The wifi namespace: saved credentials
store/settings_rf.c | The rf namespace: per-transmitter carrier and audio settings
store/settings_sys.c | The sys namespace: hostname, and whether the web runs
store/settings_internal.h | What those four share, including the carrier bracket every NVS write needs ( KI-07 )

Two seams worth knowing before you change anything here. The command
groups under cli/ each publish a table and console.c registers all of them
in one loop, so a command lives with its neighbours rather than in one long file; what any of them prints is a contract (design 07 Â§2) that the programmer tool parses, so moving a command is free and rewording its reply is not. And store/ is split one file per NVS namespace, matching the schema in design 04 Â§4: each owns its own RAM cache, its own save path and its own defaults, and none of them reads another's.

audio/dsp.c is deliberately free of ESP-IDF headers so it compiles on a host. test/host/ builds it with the test suite. If a change to dsp.c breaks that build, the change is at fault, not the test.

## 5. Storage

Four NVS namespaces, one file each under store/ . Keys are 15 characters or fewer, as NVS requires. Design 04 holds the schema table, and a new key is a change to that table in the same commit.

Namespace | Keys | Holds
radio | cnt , last , def , na0..n , ur0..n , tr0..n | Station list, last played, power-on default, per-station trim
wifi | n , s0..n , p0..n | Credentials, newest first
rf | on , hz , depth , lpf , gain , lvl , agc , agct , fdm , fdr , fdd , and the same suffixed 1 for the second transmitter | Transmitter settings
sys | host , web | The hostname, and whether the web interface runs

Stations and credentials are cached in RAM and written through, so a web handler never blocks on flash while holding anything.

Indices name a station, not a position

last and def are both indices into the station list. Any operation that renumbers the list has to carry them along, or reordering silently changes which station the board wakes up on.

settings_station_move() remaps both through remap_after_move() .
settings_station_delete() decrements them past the gap, and clears def outright if the starred station is the one deleted, because a default nobody chose is worse than none.

def is -1 when unset, in which case boot falls back to last .

## 6. HTTP API

Everything is JSON. Design 04 Â§3 is the contract.

Method | Path | Body | Returns
GET | / | | The page
GET | /api/state | | Everything. Polled once a second
GET | /api/wifi/scan | | [{ssid, rssi, secure}] . Blocking
GET | /api/discover | ?q= &by=name|tag|country | [{name, url, country, codec, bitrate, votes}] or {error}
POST | /api/station/play | {index} or {url} | {ok}
POST | /api/station/add | {name, url} | {ok}
POST | /api/station/delete | {index} | {ok}
POST | /api/station/move | {from, to} | {ok}
POST | /api/station/default | {index} , negative to clear | {ok}
POST | /api/stop | {} | {ok}
POST | /api/rf | {on, hz, depth, lpf, gain} | {ok}
POST | /api/tone | {on, hz} | {ok}
POST | /api/wifi/add | {ssid, pass} | {ok} , then reboots if from the portal
POST | /api/reboot | {} | {ok}
POST | /api/hostname | {host} | {ok}
POST | /api/web | {on: false} | {ok} , then the server stops

Every POST answers {"ok":bool} and, on failure, {"error":"ESP_ERR_..."} .
The page shows that string to the operator rather than swallowing it.

station/move performs a splice, not a swap, which is exactly drag-and-drop semantics. The UI reuses it for both the arrows and the drag.

A 404 redirects to / , which is what makes the captive portal open by itself. Captive-portal probes are frequent enough that the httpd_uri log tag is turned down to ERROR , or their warnings bury everything else.

## 7. Serial console

An esp_console REPL on the USB Serial JTAG peripheral, started before wifi_conn_start() , which blocks, so the console answers while join attempts are still running.

cli/console.c holds the REPL and the registration loop; the commands
themselves are grouped in cmd_radio.c , cmd_net.c and cmd_system.c , and
the reply convention and the argument parsers are in cli_reply.c . The grouping is for the reader: esp_console sorts its own command list, so nothing a program sees depends on which file a command lives in.

It reaches every function the page does, and design 07 Â§2 is its reference. Commands added with it end with one ok or error: line and return 0, because a non-zero return makes the REPL print a line of its own after the reply. discover runs its search on a 6 kB task created for the search, because the TLS handshake does not fit the REPL's 4 kB stack and a bigger stack would hold internal RAM permanently ( LL-07 ).

log off sets the global log level to NONE so status can be polled by a script. log on restores INFO and re-applies the httpd_uri suppression. The quiet mode is not persisted: logging is on after every boot.

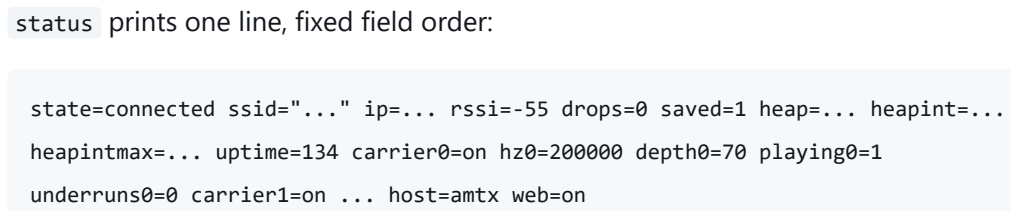
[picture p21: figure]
underruns0=0 carrier1=on ... host=amtx web=on

status prints one line, fixed field order:

state=connected ssid="..." ip=... rssi=-55 drops=0 saved=1 heap=... heapint=... heapintmax=... uptime=134 carrier0=on hz0=200000 depth0=70 playing0=1

(One line on the board; wrapped here.)

## 8. Memory

Roughly 8 MB of heap free at rest. That number is close to meaningless, and watching it instead of internal RAM cost a debugging session ( LL-07 ).

The figure that constrains this board is internal DRAM, and there is about
19 kB of it free with two chains playing. Everything scarce competes for it:
Wi-Fi buffers, DMA, task stacks and mbedTLS. Both the Diagnostics page and the CLI status line report internal free and its largest free block for exactly
this reason.

Consumer | Size | Where
Stream ring buffer | 64 kB each, 128 kB total | PSRAM
Decoder working buffers | 15 kB each, 30 kB total | PSRAM
Sample FIFO | 4 kB each, 8 kB total | Internal, and must stay there
Duty table | 1 kB each | Internal, and must stay there
Discovery reply buffer | 20 kB, transient | PSRAM
mbedTLS session | Tens of kB, transient | PSRAM, via CONFIG_MBEDTLS_EXTERNAL_MEM_ALLOC
PSRAM DMA reserve | 32 kB | Internal, reserved by IDF

The two rows marked "must stay there" are the modulation ISR's, and PSRAM is reached over SPI. Nothing on that path may live in it.

PSRAM is on. The module is an ESP32-S3R8 with 8 MB octal PSRAM, which
answers Design 06 Â§2.1, and sdkconfig.defaults sets CONFIG_SPIRAM_MODE_OCT .
The stream ring buffer moves there by itself, because stream_init() asks for PSRAM first and falls back.

Nothing on the real-time path lives in PSRAM. It is reached over SPI, so it
must never be in the modulation ISR's way: the ISR stays IRAM_ATTR and its
tables DRAM_ATTR , exactly as before.

CONFIG_SPIRAM_IGNORE_NOTFOUND keeps a board without PSRAM booting rather than failing at startup, so the default stays safe on other modules.

The tight spot is a TLS handshake. mbedTLS with the full certificate bundle
takes the largest contiguous block while it runs, so an allocation attempted
after the handshake can fail with 99 kB apparently free. discover.c claims its reply buffer before opening the connection for exactly this reason.

## 9. Traps that have already been paid for

Read this section before spending a day on any of them again.

KI-07 : an NVS write with the modulator running resets the board. See Â§3. It presented as a Wi-Fi fault for a whole session, because the setup portal is where you first try to save something. settings_set_last_station() hid it further by returning early when the index has not changed, so an ordinary boot performs no real flash write and never trips it.

LL-04 : max_redirection_count does nothing on the open() path. esp_http_client follows redirects only inside esp_http_client_perform() . A
stream cannot use perform() , so it uses open() and fetch_headers() , and the config field is never consulted. Follow them by hand: close, then
esp_http_client_set_redirection() , then open again.

KI-05 : Shoutcast v1 answers ICY 200 OK . That is not a status line esp_http_client can parse. Presenting a browser User-Agent gets a normal response.

TLS was compiled in all along. The UI carried a "TLS is not compiled in"
warning for a long time. It was wrong. CONFIG_ESP_HTTP_CLIENT_ENABLE_HTTPS
and the full certificate bundle were both set. What was missing was crt_bundle_attach on the stream client, which is a different problem with the same symptom, and the wrong note discouraged anyone from looking.

The console goes to the native USB port. CONFIG_ESP_CONSOLE_USB_SERIAL_JTAG
means a USB-to-serial bridge on the same board shows you the ROM banner and nothing more. A panic would be equally invisible there.

## 10. Limits and what would lift them

Limit | Cause | What would lift it
MP3 only | libhelix is the only decoder | EH-04
10 discovery results | Internal heap during a TLS handshake. PSRAM is now on, so this could be raised and has not been retested | Raise DISCOVER_RESULTS_MAX
20 stations | STATION_MAX | Raise it. NVS has room
Carrier below roughly 300 kHz | 8-bit duty on an 80 MHz LEDC clock | Fewer duty bits, at a cost in resolution
6.5 bits of amplitude resolution | Same | EH-05 , a faster modulation rate
No stream metadata | ICY is interleaved and not stripped | EH-08
Fading is a table rebuild | Level is baked into the duty table | Index the table by amplitude instead, making level a runtime multiply
No authentication | Not implemented | KI-06
Harmonics across medium wave | A square wave carrier | An output network. KI-02 . Not fixable in firmware

What has never been verified

The firmware runs. The audio chain is tested on a host and observed working on hardware, from an internet stream through to the duty register.

Nothing has been measured off-air. There has been no receiver, no scope and no spectrum analyser on this project at any point. The RF behaviour, the harmonic content, the modulation quality and the actual radiated field are all
unobserved. Design 06 lists what else was assumed.

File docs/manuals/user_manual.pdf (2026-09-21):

# User Manual

Everything you can do with the transmitter once it is built and on your network. To get to that point, see the Installation Manual.

The board has no display, no buttons and no knobs. You drive all of it from a web page it serves itself, at http://amtx.local or at its IP address, or
from the serial console, which can do everything the page can.

## Contents

1. The page at a glance
2. Now playing
3. Stations
4. Discover
5. Transmitter
6. Network
7. Diagnostics
8. Tuning a receiver
9. The serial console
10. Before you transmit


The built transmitter: the lid carries the two loop windings and their series resistors, the base carries the board. docs/images/wiring.svg is what is wired to what.

## 1. The page at a glance

There are two independent transmitters, A and B. Each plays its own station on its own carrier frequency, out of its own pin, with its own modulation settings. They share your station list and your Wi-Fi.

Six tabs across the top, and a header that always shows both carriers.

A ON AIR 200.0 kHz 70% B ON AIR 250.0 kHz 70%

Amber is A, blue is B. Grey and reading OFF means that carrier is not running. The numbers are the carrier frequency and the modulation depth.

Below the tabs is an Acting on bar with two buttons. Whichever transmitter is selected there is the one the Stations, Discover and Transmitter tabs act on. Now playing and Diagnostics always show both, because what is on air is the question you want answered without clicking anything.

Every button reports back. Press one and it indents, then a message slides up from the bottom of the screen telling you what happened. A red message means the transmitter refused, and it says why. This matters more than it sounds:
with no display on the board, that message is the only confirmation you get that a press did anything at all.

Two actions restart the board, so they raise a dialog you have to dismiss rather than a message that fades. Both are on the Network tab.

## 2. Now playing

The station name, its URL, and a Modulation meter.

The meter shows the peak level going into the modulator. Green is normal.
Amber above 80% means you are running hot. Red above 97% means the limiter is working hard and the sound will suffer. If it sits red, lower the programme
gain on the Transmitter tab.

One card per transmitter, each with its own controls.

Stop stops that transmitter's audio. Its carrier stays up, unmodulated, so a receiver tuned to it hears silence rather than losing the station. The other transmitter is untouched.

Carrier switches that output on and off. The button says what pressing it will do.

Play a URL directly takes any HTTP MP3 stream address and plays it without saving it. Use it to try a station before you keep it.

## 3. Stations

Your saved list, up to 20 stations.

Each row has a drag grip, the name and URL, and five controls.

Control | What it does
â˜… | Makes this the station the transmitter plays at power-on
Play | Tune to it now
% | Level trim for this station, 10 to 400%. For when the AGC gets one wrong
â†‘ â†“ | Move it one place
Ã— | Delete it

Ordering

Drag a row by any part of it and drop it where you want it. The order is saved as you go, so it survives a power cut.

The arrows do the same job. Keep them in mind on a phone or tablet, where dragging does not work: HTML5 drag-and-drop is a mouse feature and touch browsers do not implement it.

The power-on station

Press the star on a row and that station becomes the one the selected transmitter tunes when it powers up. The star turns amber. Press it again to clear it.

Each transmitter has its own star. Switch between A and B on the Acting on bar and the stars change to show that transmitter's choice, so you can have A come up on one station and B on another.

With no star set, the board comes back on whatever it was playing when it lost power. With a star set, it always comes back on that station, whatever was playing before.

The star follows its station when you reorder the list. Drag the starred
station from the bottom to the top and it stays starred. Delete the starred station and the star clears rather than jumping to a neighbour, because a default nobody chose is worse than none.

Adding by hand

Type a name and a stream URL and press Add. The URL must be plain HTTP or HTTPS to an MP3 stream. Playlist files ( .pls , .m3u ) are not parsed, and
HLS streams ( .m3u8 ) will connect and then stop, because the firmware expects a continuous MP3 byte stream.

## 4. Discover

Search a community directory of internet radio stations rather than hunting for URLs yourself.

Type something, choose whether it searches by name, genre or country, and press Search. Results come back ordered by how many people listen to them. Each row offers:

Play, which tunes to it now without saving.
Save, which adds it to the end of your station list.

Results are limited to ten. That was a memory limit: a secure connection to the directory takes tens of kB while it runs, and each result is roughly
1.5 kB of data, which once exhausted the internal RAM. PSRAM is enabled now, so the limit could probably be raised, but it has not been retested and the
cap still stands. Narrow the search rather than expecting more rows.

Two filters are applied for you, and both reflect what the firmware can actually play:

MP3 only. It is the only decoder compiled in. An AAC or OGG station would save cleanly and then play silence.
Plain HTTP only. Encrypted streams are filtered out at the directory.

## 5. Transmitter

The RF settings. Press Apply and save to commit them. They persist.

Setting | Range | What it does
Carrier | 60 to 300 kHz | The frequency you tune the receiver to
Modulation depth | 5 to 90% | How far the envelope swings
Audio low-pass | 500 to 9500 Hz | Where the audio is cut off
Programme gain | 0 to 400% | Level into the limiter
Carrier output | On or off | The output itself

These act on the transmitter selected in the Acting on bar. The panel border shows which: amber for A, blue for B.

Carrier. A defaults to 200 kHz and B to 250 kHz, both in the longwave
band. Not every frequency you type will be accepted. The hardware divides an 80 MHz clock and needs 256 duty steps per cycle, so 312.5 kHz is a hard ceiling and the medium-wave band is out of reach at this duty resolution.
Ask for 800 kHz or 1.2 MHz and the transmitter refuses and keeps the frequency it had. The message tells you.

Keep the two carriers apart, and mind the harmonics: 200 kHz has its third harmonic at 600 kHz, so a second carrier is not the only thing sharing the
air with the first.

Modulation depth. 70% is a good starting point. Above 75% the trough pinches the carrier and an envelope detector, which is what a cheap AM radio is, turns that into distortion. The setting allows more so you can hear the effect. It is not an improvement.

Audio low-pass. 4500 Hz keeps the transmission inside a 9 kHz channel. Raising it makes the audio brighter and puts energy into the next channel along, where it becomes someone else's problem.

Programme gain. Broadcast AM runs hot, and 140% is the default for that reason. Watch the modulation meter on the Now playing tab. If it sits red, come down.

Carrier level. How hard the transmitter drives, 5 to 100%. This is the honest way to turn the power down: it shrinks the whole radiated envelope, rather than turning the audio down and leaving the carrier at full strength. It costs resolution, because the envelope then uses fewer duty steps, so at 25% there is a quarter of the amplitude resolution there was at 100%. Use it to keep the field small; use programme gain and the AGC to control loudness.

Loudness AGC

Stations differ by more than 10 dB in average level. Measured on this board: Jazz Blues averaged 0.738 while Radio Swiss Jazz averaged 0.213, on identical settings. A compressed music service runs near full scale, a jazz service with real dynamic range averages far lower, and speech with pauses lower still.

The limiter cannot fix that, because a limiter only pushes peaks down and never lifts quiet material up. The AGC tracks the programme average and rides the gain to a target, which is what broadcast AM processing does and why AM stations all sound equally loud. With it on, those two stations came to within 1.9 dB of each other.

It shows what it is doing beside the switch, as a gain in dB.

Target level is what it aims the average at. 25% is a good default. Higher is louder and closer to the limiter.

It trades dynamic range for loudness, which is the same bargain every broadcaster makes. Switch it off per transmitter if you would rather keep the dynamics. For the odd station it gets wrong, use the per-station trim: the percentage button on the station row.

Fading

For fun, and for realism. Wanders the carrier level so the signal comes and goes the way a distant station does. It acts on the carrier rather than the audio, so the noise floor rises and falls with it, exactly as propagation does.

Mode | What it sounds like
Slow fade | Long, lazy fades. Try 0.05 to 0.2 Hz
Flutter | Faster wobble. Aircraft flutter, aurora. Try 3 to 10 Hz
Random drift | Three unrelated rates summed, so it never repeats. The most convincing

Rate sets the speed and Depth how far down it dips. 100% depth takes
the carrier to nothing at the bottom of the fade.

It costs nothing when off.

Test tone

Replaces the programme with a steady tone at the modulator's own rate. Put a scope on the RF pin and you see the envelope with the decoder and the network taken out of the picture. Useful for checking the output stage without
wondering whether the stream is at fault.

## 6. Network

The top panel shows the state, the network, the address, the signal strength and how many times the connection has dropped.

Scan for networks lists what the board can see, with signal strengths. Press Use on one to fill in the name. Only 2.4 GHz networks appear, because that is all the radio has.

Password has an eye button beside it. Press it to read what you typed before you commit, which saves a reboot cycle spent wondering.

Save and join stores the credentials and restarts to join. The page will lose contact. That is expected, and the dialog says so.

Reboot restarts the transmitter.

Hostname is the name the board answers to, http://<name>.local . Every board starts as amtx , so with two on one network, give each its own name or only one of them answers. Letters, digits and hyphens, up to 31. The new name works at once; the router's device list shows it after a reboot.

Turn off the web interface stops this page altogether, for a network you
do not trust: the page has no password. It asks first, because the page
cannot turn itself back on. Only the serial console can, with web on , and
while the web is off there is no setup portal either.

On a phone held upright a banner asks you to turn it sideways. The page works upright, but it is laid out for landscape. Dismiss the banner with its Ã—.

Starting again from nothing

Hold the board's BOOT button for five seconds while it is running. The button is marked B; the other one, R, is RESET and cannot do this.

The transmission stops, and the board restarts as if it were new: no stations but the two it was built with, no saved networks, default transmitter settings, the name amtx , and the web interface back on. Then it raises the AMTX-Setup access point and waits to be set up again, as in the Installation Manual Â§6.

Let go before five seconds and nothing happens at all. If the serial console is connected it counts down while you hold it.

The same thing, from further away:

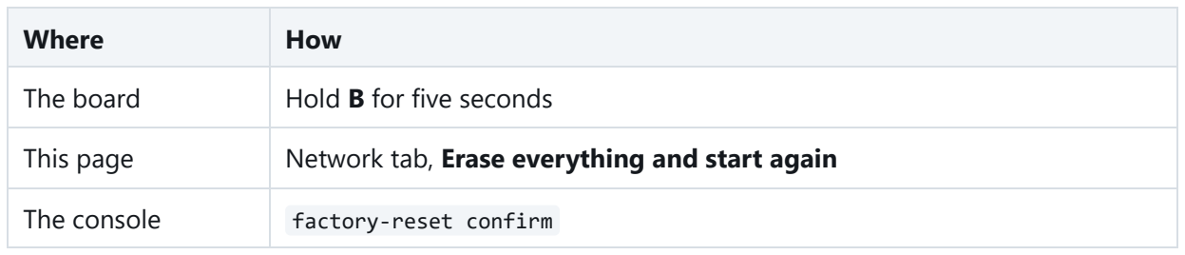
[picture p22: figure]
Where; How; The board; Hold B for five seconds; The console; factory-reset confirm

This page | Network tab, Erase everything and start again

It is the way back when the page cannot be reached at all: a board whose saved network no longer exists, or one whose web interface was turned off on a network that has since gone. It does not touch the firmware, only what the board remembers.

## 7. Diagnostics

Everything the board knows about itself. Worth reading when something sounds wrong.

Row | What to look for
Stream buffer | Should hover, not sit empty or pinned full
HTTP status | 200 when playing
Reconnects | Climbing means an unreliable station
Last error | The reason the stream last stopped
Decoded frames | Should climb steadily, roughly 40 per second
Decode errors | A few at the start are normal. Climbing is not
Stream format | Sample rate, channels and bitrate the station is sending
Resampler trim | Parts per million of correction. Near 5000 means the source rate is far from what the chain expects
AGC gain | What the loudness AGC is adding or removing right now, in dB
Modulator FIFO | Should sit near half full
Modulator underruns | Should stop climbing once a station is playing
Free heap | Falling steadily over hours would suggest a leak
Uptime | Resets to zero if the board restarted without you asking

The most useful pair is decoded frames and modulator underruns. Frames climbing with underruns static means the whole chain is healthy.

## 8. Tuning a receiver

Set the receiver to the carrier frequency shown in the header. With the default 200 kHz you need a longwave radio: most portable radios sold outside Europe are medium-wave and FM only, and will not reach it.

Hold the receiver near the loop. Signal falls off very quickly with distance, which is the point.

If you hear the station on the receiver but the sound is distorted, try lowering the modulation depth, then the programme gain.

If you hear nothing, check the header says ON AIR , check Now playing shows a station and the modulation meter is moving, then check your output network.

## 9. The serial console

Connect the native USB port and open a terminal at 115200 baud. Press Enter for the amtx> prompt. It works whether or not Wi-Fi is up, which is the point of it: the web page is unreachable exactly when the network is the thing that is broken.

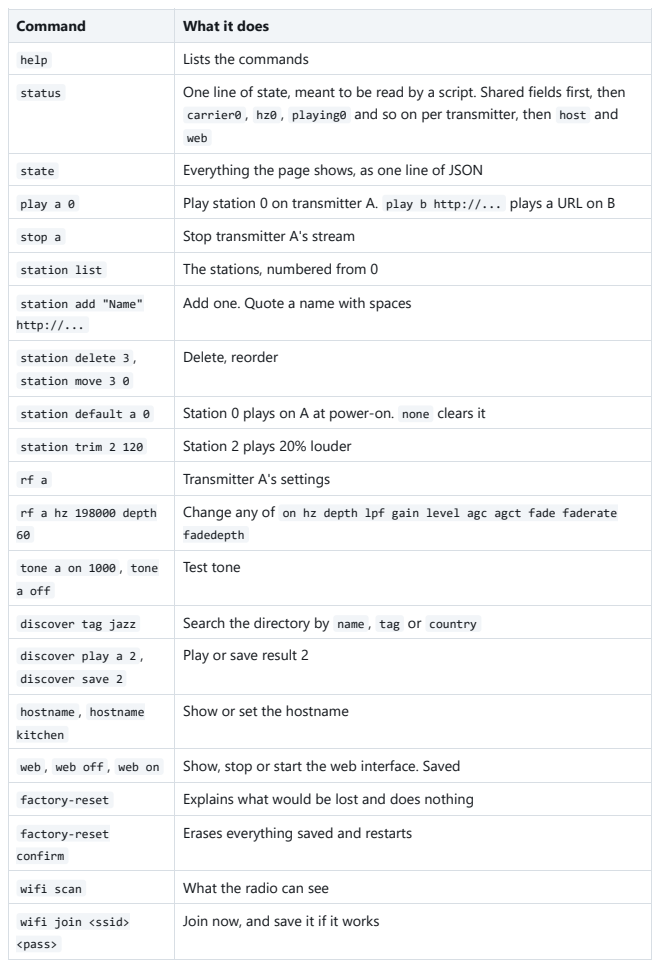
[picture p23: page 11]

Command | What it does
help | Lists the commands
status | One line of state, meant to be read by a script. Shared fields first, then carrier0 , hz0 , playing0 and so on per transmitter, then host and web

state | Everything the page shows, as one line of JSON
play a 0 | Play station 0 on transmitter A. play b http://... plays a URL on B
stop a | Stop transmitter A's stream
station list | The stations, numbered from 0

station add "Name" http://... | Add one. Quote a name with spaces

station delete 3 , station move 3 0 | Delete, reorder

station default a 0 | Station 0 plays on A at power-on. none clears it
station trim 2 120 | Station 2 plays 20% louder
rf a | Transmitter A's settings

rf a hz 198000 depth 60 | Change any of on hz depth lpf gain level agc agct fade faderate fadedepth

tone a on 1000 , tone a off | Test tone

discover tag jazz | Search the directory by name , tag or country

discover play a 2 , discover save 2 | Play or save result 2

hostname , hostname kitchen | Show or set the hostname

web , web off , web on | Show, stop or start the web interface. Saved
factory-reset | Explains what would be lost and does nothing

factory-reset confirm | Erases everything saved and restarts

wifi scan | What the radio can see

wifi join <ssid> <pass> | Join now, and save it if it works

Command | What it does
wifi save <ssid> <pass> | Save without joining
wifi list | Saved networks
wifi forget | Delete all saved networks
log off | Stop the log scrolling past
log on | Start it again
reboot | Restart

wifi join tries for up to 15 seconds. It retries by itself when the router misses a frame or a scan misses the network. When it gives up, it says why:

Message | Usually means
reason 201, no network with that name | A typo. Names are case-sensitive; copy it from wifi scan
reason 15 or 204 , wrong password | The password, or its case
reason 2, router did not answer authentication | The router ignores the board. Check for a MAC filter on the router; the board's MAC is in the boot log
reason 210 or 211, network security not supported | The router is WPA3-only. Allow WPA2 as well

Every command except status , log and reboot finishes with a line
starting ok or error: , which says whether it worked. tools/amtx-programmer/ drives the board through them with buttons and dialogs.

log off is there so the console can be driven by a script. With the log
quiet, status returns a single parseable line and nothing else. Logging
comes back on at every boot, because a silent board looks like a dead one.

The baud rate does not really matter. The console is a USB device rather than a real serial port, so the setting is negotiated away.

## 10. Before you transmit

This is a transmitter, and two facts about it are not negotiable.

Fit an output low-pass network to each pin. Without it, a square-wave carrier radiates harmonics across the whole medium-wave band and interferes with every station a domestic radio can tune. Design 03 Â§4 has a network that works. With two transmitters you need two of them: coupling both pins into one network lets the carriers intermodulate, and the products land where neither carrier is.

Keep the field inside the room. The default 200 kHz sits in the longwave broadcast band, 2 kHz from BBC Radio 4 on 198 kHz. Use an inductive loop beside the receiver, not an antenna. Deliberate radiation there is licensed in the UK and in most other places, and this project holds no licence. What you radiate, and the rules where you live, are yours to check.

Nothing in this project has been measured off-air. The audio chain is tested and the firmware runs, but what the pin actually radiates has never been observed on a receiver or an analyser.

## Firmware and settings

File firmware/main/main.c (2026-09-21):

/* main.c: bring-up order, and nothing else.
 *
 * The order matters more than it looks:
 *
 *   1. NVS, so everything below can read its saved settings.
 *   2. Wi-Fi, which blocks until a network joins or the setup portal is up.
 *   3. The web interface, on whichever of the two is running, unless the
 *      operator has turned it off. Then there is no portal either, and the
 *      serial console, started before step 2, is the way in (design 07 §4).
 *   4. The audio and RF stack, started from a task pinned to core 1. The
 *      modulation ISR is allocated on the core that registers it, and the
 *      sample FIFO's lockless contract assumes the decode task and the ISR
 *      share a core, so this cannot be done from app_main (core 0).
 */

#include "am_config.h"
#include "app.h"
#include "button.h"
#include "cli/console.h"
#include "esp_log.h"
#include "esp_system.h"
#include "freertos/FreeRTOS.h"
#include "freertos/task.h"
#include "net/webui.h"
#include "net/wifi_conn.h"
#include "store/settings.h"

static const char *TAG = "amtx";

static void audio_startup_task(void *arg)
{
    (void)arg;

    const esp_err_t err = app_init();
    if (err != ESP_OK) {
        /* The web UI is already up on core 0, so the operator can still see
         * the board and read the log rather than facing a silent brick. */
        ESP_LOGE(TAG, "audio and RF stack failed to start: %s",
                 esp_err_to_name(err));
    }
    vTaskDelete(NULL);
}

void app_main(void)
{
    ESP_LOGI(TAG, "ESP32-S3 AM Transmitter");
    ESP_LOGI(TAG, "carrier GPIO %d, %d Hz nominal, %d Hz modulation rate",
             RF_CARRIER_GPIO, RF_CARRIER_HZ, AM_SAMPLE_RATE_HZ);
    ESP_LOGW(TAG, "this radiates in a licensed broadcast band: keep the field "
                  "inside the room and fit the output filter (see "
                  "docs/design/03_hardware.md)");

    ESP_ERROR_CHECK(settings_init());
    ESP_ERROR_CHECK(wifi_conn_init());

    /* Before wifi_conn_start(), which blocks: the console is the one way in
     * when the network is the thing that is broken, so it must not wait on
     * the network coming up. */
    ESP_ERROR_CHECK_WITHOUT_ABORT(console_start());

    /* Before it too, and for the same reason. A board whose saved network no
     * longer exists spends 15 seconds per credential in wifi_conn_start(), and
     * the button that rescues it should work during that wait rather than
     * after it (design 07 §7). */
    ESP_ERROR_CHECK_WITHOUT_ABORT(button_start());

    /* Blocks: walks the saved networks, then falls back to the setup AP if
     * the web interface is on to serve it. */
    const bool web = settings_web_enabled();
    wifi_conn_start(web);

    if (web) {
        ESP_ERROR_CHECK(webui_start());
    } else {
        ESP_LOGW(TAG, "web interface is off: use the serial console, and "
                      "'web on' to bring the page back");
    }

    xTaskCreatePinnedToCore(audio_startup_task, "audiostart", 4096, NULL, 5,
                            NULL, TASK_CORE_AUDIO);
}

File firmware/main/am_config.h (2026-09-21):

/* am_config.h: every tunable in one place.
 *
 * Each value is #ifndef-guarded, so Kconfig (main/Kconfig.projbuild) or a
 * -D on the command line wins over the default here. Nothing else in the
 * firmware may hard-code a pin, a frequency, or a buffer size: add it here
 * and in Kconfig, or in neither.
 *
 * The RF numbers are a hardware-software contract. Changing one without
 * updating docs/design/03_hardware.md is a defect, not a tweak.
 */
#pragma once

#include "sdkconfig.h"

/* ---------------------------------------------------------------- network */

/* Fallback credentials, used only if NVS holds none. Leave empty and use the
 * SoftAP setup portal instead; never commit a real password. */
#ifndef WIFI_SSID
#define WIFI_SSID CONFIG_AMTX_WIFI_SSID
#endif
#ifndef WIFI_PASS
#define WIFI_PASS CONFIG_AMTX_WIFI_PASS
#endif

/* The two stations a factory-fresh device seeds, one per transmitter, each
 * made that transmitter's power-on station. Any HTTP (not HTTPS) MP3
 * shoutcast/icecast endpoint. Design 07 section 5. */
#ifndef STATION_A_NAME
#define STATION_A_NAME CONFIG_AMTX_STATION_A_NAME
#endif
#ifndef STATION_A_URL
#define STATION_A_URL CONFIG_AMTX_STATION_A_URL
#endif
#ifndef STATION_B_NAME
#define STATION_B_NAME CONFIG_AMTX_STATION_B_NAME
#endif
#ifndef STATION_B_URL
#define STATION_B_URL CONFIG_AMTX_STATION_B_URL
#endif

/* The hostname until the operator sets one, for mDNS (http://amtx.local) and
 * DHCP. Changeable at run time and saved in NVS, because two boards on one
 * network cannot both be amtx.local. Design 07 section 3. */
#ifndef AMTX_HOSTNAME
#define AMTX_HOSTNAME "amtx"
#endif
/* Buffer size including the terminator: 31 characters of name. */
#define HOSTNAME_MAX 32
#ifndef AMTX_AP_SSID
#define AMTX_AP_SSID "AMTX-Setup"     /* provisioning SoftAP */
#endif

/* The BOOT button, GPIO 0 on the ESP32-S3-Zero. Held this long while the board
 * is running, it erases NVS and restarts: design 07 section 7, which also
 * explains why the gesture cannot be a press at power-on (that belongs to the
 * ROM's download mode) and why RESET cannot be read at all.
 *
 * Five seconds is longer than any accidental press and shorter than anyone's
 * patience. A brief press does nothing. */
#ifndef AMTX_FACTORY_BUTTON_GPIO
#define AMTX_FACTORY_BUTTON_GPIO CONFIG_AMTX_FACTORY_BUTTON_GPIO
#endif
#ifndef AMTX_FACTORY_HOLD_MS
#define AMTX_FACTORY_HOLD_MS CONFIG_AMTX_FACTORY_HOLD_MS
#endif

/* The serial console is the only diagnostic on a board with no display, and
 * the interesting question during setup is always the same one: is it on the
 * network, and at what address? Say so on a fixed cadence, so silence on the
 * monitor means "nothing is running" rather than "nothing has changed".
 * 0 disables the heartbeat. */
#ifndef AMTX_WIFI_HEARTBEAT_S
#define AMTX_WIFI_HEARTBEAT_S 30
#endif

/* Redirect hops a station URL may take before the stream gives up. CDN
 * hand-offs and http-to-https promotions routinely take two. */
#ifndef STREAM_REDIRECT_MAX
#define STREAM_REDIRECT_MAX 5
#endif

/* 64 KB of raw MP3 in flight: about 4 s at 128 kbit/s. Absorbs network
 * jitter so the decoder never starves on a slow TCP window. */
#ifndef STREAM_RINGBUF_BYTES
#define STREAM_RINGBUF_BYTES (64 * 1024)
#endif

/* ----------------------------------------------------------------- RF path */

#ifndef RF_CARRIER_GPIO
#define RF_CARRIER_GPIO CONFIG_AMTX_RF_GPIO
#endif

/* Two independent transmitters: two carriers, two stations, two sets of audio
 * settings. They share only the 20 kHz modulation timer and the 80 MHz LEDC
 * clock. Each needs its own output low-pass network; a shared one lets them
 * intermodulate, and the third harmonic of a 200 kHz carrier lands at 600 kHz
 * where a second carrier might well be. */
#ifndef RF_CHAINS
#define RF_CHAINS 2
#endif

#ifndef RF_CARRIER_GPIO_B
#define RF_CARRIER_GPIO_B CONFIG_AMTX_RF_GPIO_B
#endif

/* Chain B's default. Kept clear of chain A's 200 kHz and of its own harmonic
 * relationship to it: 250 kHz is not an integer multiple of 200 kHz, so the
 * two do not reinforce each other's spurs. Both are inside the reachable
 * range, which at 8-bit duty on an 80 MHz clock tops out at 312.5 kHz. */
#ifndef RF_CARRIER_HZ_B
#define RF_CARRIER_HZ_B 250000
#endif

/* 200 kHz sits in the longwave broadcast band (148.5-283.5 kHz), 2 kHz from
 * BBC Radio 4 on 198 kHz. See KI-04: keep the field local. */
#ifndef RF_CARRIER_HZ
#define RF_CARRIER_HZ 200000
#endif

/* 8 bits = 256 duty steps per carrier period. At 200 kHz on the 80 MHz LEDC
 * clock this is the hardware ceiling: 80e6/200e3 = 400 clocks per period, so
 * 9 bits (512 steps) will not fit. */
#ifndef RF_DUTY_RES_BITS
#define RF_DUTY_RES_BITS 8
#endif
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

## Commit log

2026-09-21 ESP32-S3 AM transmitter, v1.0
    Internet radio over Wi-Fi, re-broadcast as an amplitude-modulated longwave
    carrier on a GPIO pin, for an ordinary AM receiver in the same room. Two
    independent transmitters on one board, driven from a web page it serves itself
    or from a serial console, in a printed case whose lid carries both loop
    windings.
    This is the public mirror of a working repository: source, tools, manuals,
    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
    [partitions.csv, tx-case.base.step, tx-case.base.stl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]
2026-09-21 Add a project page, with the demo film
    docs/index.html, served by GitHub Pages: what it is, the film of the set on the
    shelf being tuned by hand, the wiring diagram, photographs of the built unit,
    renders of the printed parts, the one-line flash command, the manuals, and the
    two warnings this project will not publish without.
    It also carries the section that matters most on a page like this: what has
    been tested and what has not. Runs, printed, untested, unmeasured, in those
    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
2026-10-07 add the Quick Start manual, and point the page and README at it
    The four manuals all assumed you were building something: the Installation
    Manual opens at "install ESP-IDF", the Build Manual at a 3D printer. The only
    route for someone who had just downloaded a release was the page's one-line
    esptool recipe, which is a recipe and not a guide.
    Quick Start covers that gap. Release zip to audio out of a receiver with no
    compiler: install Python, pick the right one of the board's two USB sockets,
    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
